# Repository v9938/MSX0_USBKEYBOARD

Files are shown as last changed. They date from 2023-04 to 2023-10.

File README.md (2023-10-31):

# MSX0 USB-Keyboard MBUS Stack  

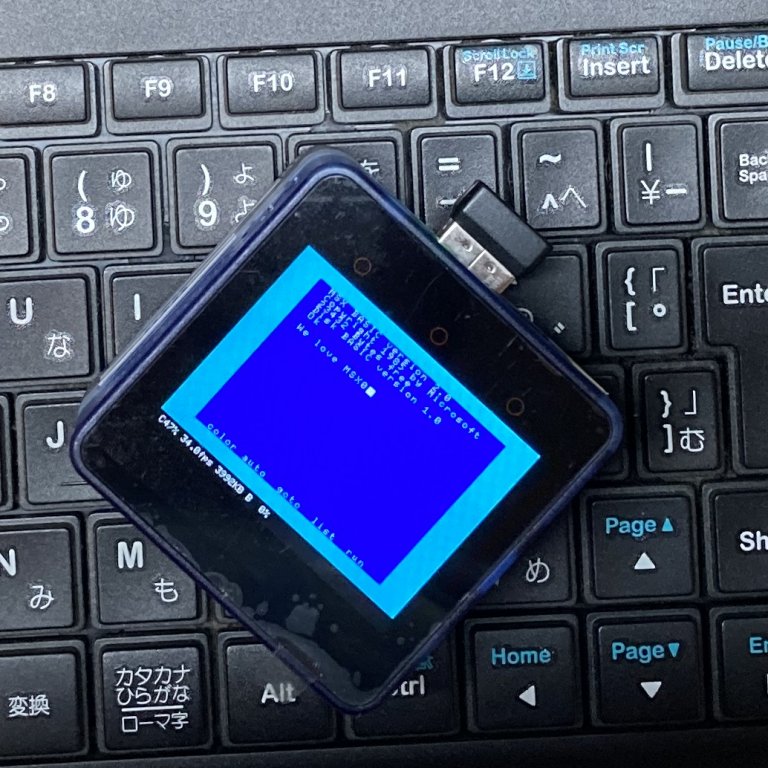
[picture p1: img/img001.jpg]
装置イメージ
  

MSX0 USB-Keyboard MBUS Stackは、別売のM5 Stack USB Module with MAX3421Eと一緒に使用することで  
M5 Faces Keyboard または Game Padと同等の機能を、USBキーボードやゲームパッドで実現するStackです。  
MSX0のKEYBOARDモードおよびGAME PADモードの両方に対応しています。  

## ■ MSX0製品版への対応について
(10/26更新）  
MSX0製品版(ver:0.05.04)への本製品の対応ですが、新しいスケッチに更新することで対応可能です。  

### Firmware (USB KEYBOARD版)
[USB KEYBOARD/MSX JOYSTICK対応版 Firmware](./Arduino/USBHIDBootKbd_MSX0/)  

sketchの書き込み方法は組み立て説明書の「Arduinoスケッチの書き込み」を参照ください。  
[組み立て説明書](./AssemblyManual/Assembly.md)

### 仕様上の制約について
動作は旧KEYBOARD仕様に準拠するため複数キーや押しっぱなしのキー認識が出来ません。  
また、MSX0の仕様上、旧キーボードモードでは本体Grove I2C_A端子との併用ができません。  
（Device I/O Error、またはMSX0の動作が止まります)

なお、新キーボードモードへの対応はKEY割り込み通知の信号が物理的に変わってしまったため、  
当該アダプタでは対応が不可能です。新基板にて対応を計画しています。ご了承ください。  

### キーボードモードとゲームパッドモードの切り替えについて
USBキーボードを接続していない場合やM5 USBモジュールを接続していない状態で起動した場合は  
GamePadモードになります。電源が入った状態で、USBを抜差すると一時的に動作がおかしくなる場合が  
ありますが、その際はMSX0をリセットしてください。  

## ■ 2種類のStack
頒布しているStackは、13mmと6.5mmの厚みが異なる2種類を頒布しています。  
この2つのStackは使用するFirmwareは一緒ですがMSX仕様のジョイスティック対応の有無の差があります。

### 共通機能  
USB KEYBOARD/JOYSTICK → MSX0 Keyboard変換  

### 6.5mm厚Stack
Socketの高さが違います(M5Stack用2 x 15ピンソケット)  
付属フレームがM5純正の成形品です　(M5 Plastic Frame for Proto Module)  

### 13mm厚Stack
MSX仕様JOYSTICK(DSUB9ピン) → MSX0 GamePad変換機能が追加されます。  
当該機能はStack単体でもMSX仕様のJOYSTICKの変換として使用することができます。  

Socketの高さが違います(M5-13.2モジュール用 ソケット)  
付属フレームは、オリジナルの3Dプリント品になります。　　

## ■ 使用イメージと基板写真

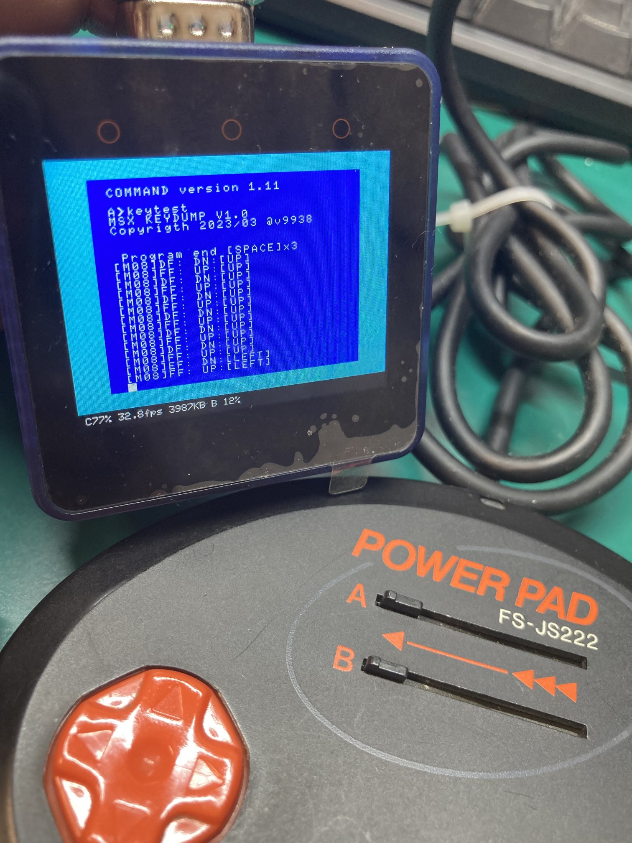
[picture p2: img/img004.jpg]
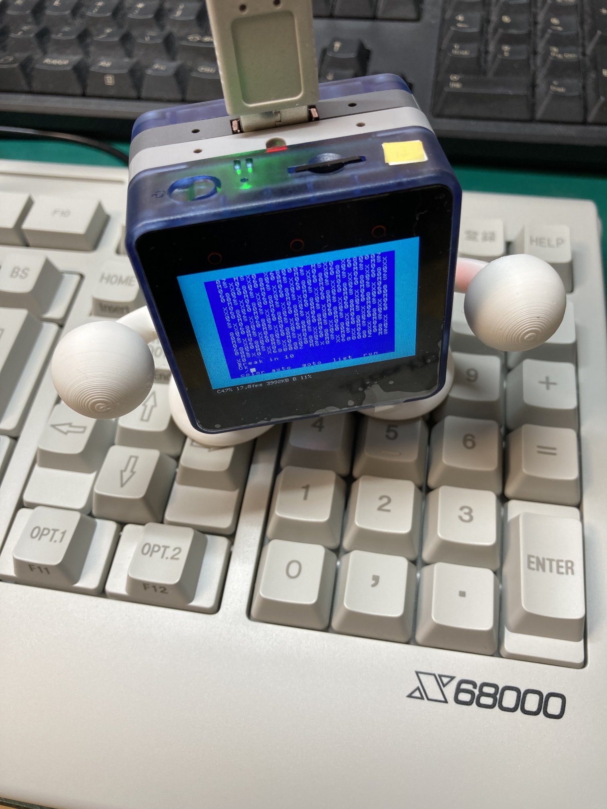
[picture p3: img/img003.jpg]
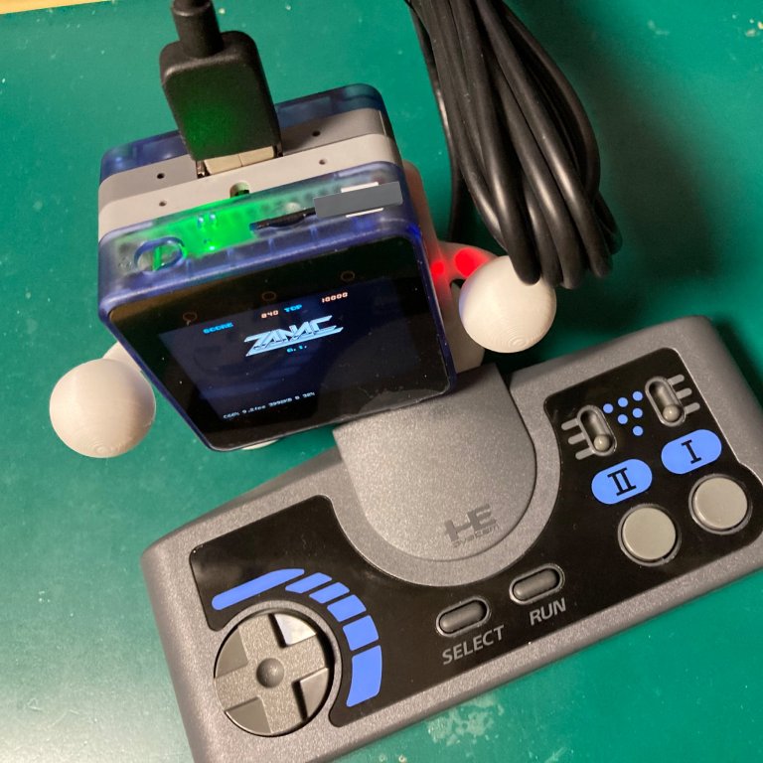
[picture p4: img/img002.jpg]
   
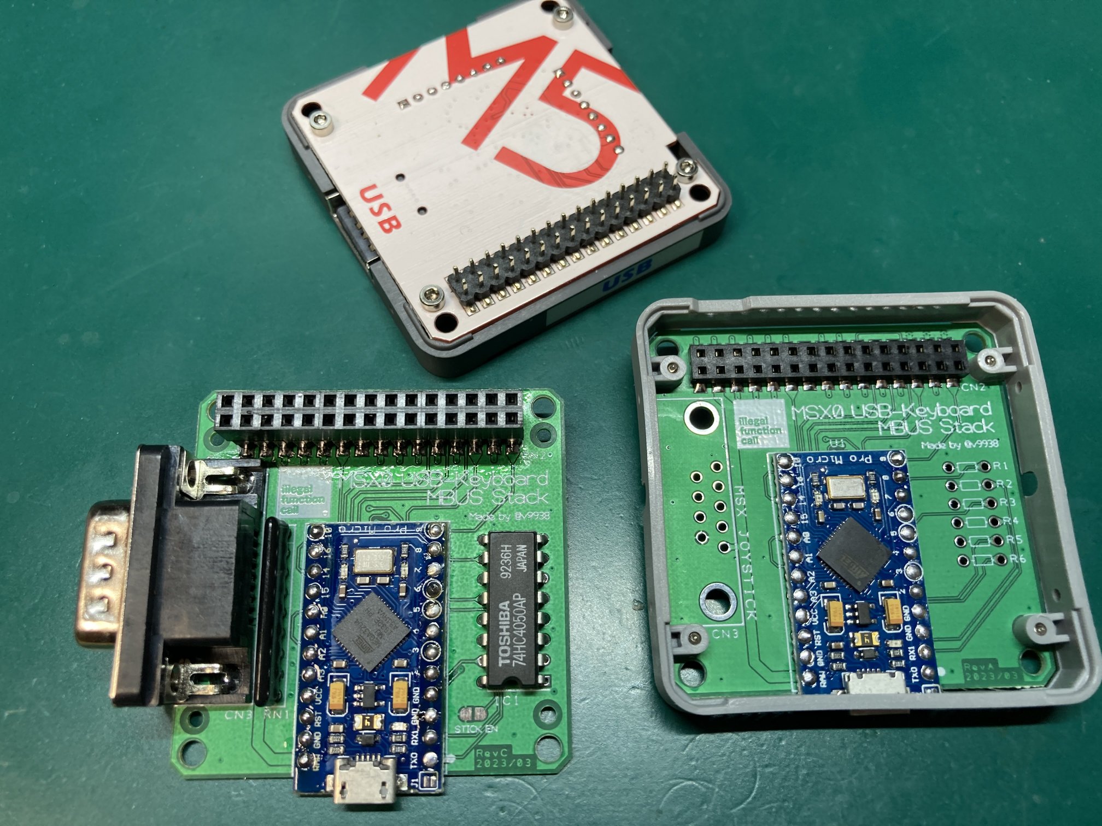
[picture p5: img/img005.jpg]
   

実際の動作は下記URLを参照してください。  
<https://twitter.com/i/status/1641843307184799746>  
<https://twitter.com/i/status/1641485580763807744>  

## ■ MSX0のキーボード実装仕様について   
現在配布中のMSX0では、MSXキーボードのキーボードについて全キーの割り付けがされていません。  
キーボードモードでは16msのみ当該キーがトグルされる仕様になっています。  
またゲームコントローラーモード以外で複数キーの同時入力および押し続けを行う事ができません。  

出来る限りオリジナルに近いキー配置や操作感にしたいのですが、MSX0の仕様により全く異なる操作感  
になる事をあらかじめご了承ください。  

本問題については、MSX0側の改良で改善される場合は本Stackも対応したいと思います。

## ■ MSX0のキーコード表   
本機は、以下のキーコード表を元に設計しました。  

#### I2Cアドレス 0x08　　
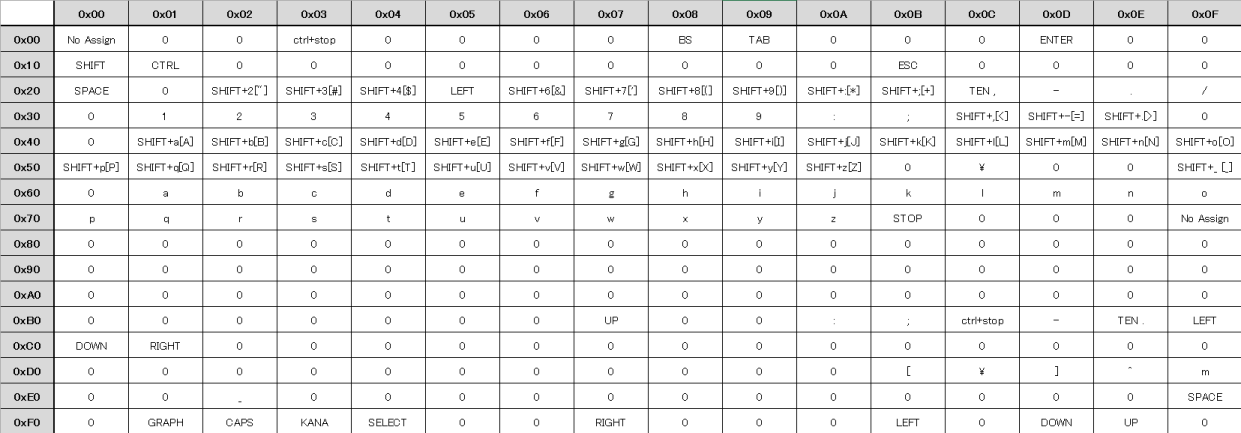
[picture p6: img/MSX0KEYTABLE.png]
  
[キーマップ (EXCEL形式)](./img/MSX0KEYTABLE.xlsx)
## ■ USBキーボードについて   
日本語対応USB 108/109キーボードに対応しています。  
Logicool社のUnifyingでの動作も確認できていますが、  
当該レシーバのように電源投入から立ち上がりが遅いキーボードは、  
電源投入直後のみ誤ってゲームパッドモードで認識される場合があります。  

その場合は、MSX0側のリセットボタンを押してMSX0を再起動するか、  
Configのキー設定をキーボードモード固定してください。  

<!-- 写真： -->

### 動作確認済みUSBキーボード
hp USBスリムスタンダードキーボード(日本語版109Aキーボード) N3R87AA#ABJ  
MSソリューションズ　MS-USBKBJP109BK  
Logicool Wireless Touch Keyboard K400  
Microsoft Wired keyboard 600
東プレ REALFORCE 108UBK SJ08B0  

## ■ USBゲームコントローラについて   
USBキーボード対応とファームが異なりますのでこちらを使う場合はファームを書き換えてください。  
USBゲームコントローラは以下の機種に対応しています。

### 動作確認済みUSBゲームコントローラ
SEGA Genesis Mini 3-Button Classic Controller MK-16500  
SEGA ファイティングパッド6B HAA-2552  
KONAMI(HORI) PCエンジンminiコントローラー HTG-002  
KONAMI(HORI) ターボパッド for PCエンジン mini HTG-003  
KONAMI(HORI) Core Grafx Mini mini Turbo Controller HTG-006  
SONY プレイステーション クラシック付属コントローラ SCPH-1000R  
8BitDo SN30 Pro  
SEGA アストロシティミニ コントロールパッド  
TAITO イーグレットツーミニ コントロールパッド  
TAITO イーグレットツーミニ コントロールパネル  
Matflash F300 Elite  
SONY PS4 DUALSHOCK 4 (CUH-ZCT2J)  
HORI FIGHTING STICK MINI  

## ■ 頒布するキットについて   

本製品は原則半田付けが必要なキット形式の頒布になります。  

家電のKENちゃん、SwitchScienceさんにて取り扱い予定です。  
配布の形態は、下記2形態になります。  

#### フルキット（基板 ＋ pro micro互換品 ＋その他パーツ ＋フレーム）
必要なパーツも、すべてセットになったキットです。  
パーツのハンダ付けとファームウェア書き込みの為にArduinoの開発環境が必要です。  

M5 Stack USB Moduleは別途購入してください。  
<https://shop.m5stack.com/products/usb-module>  
<https://www.switch-science.com/products/6061>  

#### 完成品（半田付け済、M5 Stack USB Module付属)
家電のKENちゃんのみの扱いになります。  
組み立て済で直ぐ使える状態になっています。  

## ■ 頒布先   

### フルキット
### ○6.5mm厚 USBのみ対応

#### Switch Science  
URL未定
<!-- <https://> -->

### ○13mm厚 MSX規格ジョイスティックポート有り

#### Switch Science  
URL未定
<!-- <https://> -->

### 完成品
### ○6.5mm厚 USBのみ対応
#### 家電のKENちゃん  
<https://www.kadenken.com/view/item/000000001590>

### ○13mm厚 MSX規格ジョイスティックポート有り
#### 家電のKENちゃん  
<https://www.kadenken.com/view/item/000000001589>

## ■ 組み立て説明書について  
[組み立て説明書](./AssemblyManual/Assembly.md)

## ■ 動作チェックソフト  
下記ツールでMSXからキーボード各キーの押した状態の確認を行う事ができます。  
[MSX-DOS KEYMATRIX チェックツール](./MSXKEYDUMP/keydump.com)

## ■ 本機の仕様について

|仕様  | 詳細 |
| - | - |
| 対応規格 | M5 module MBUS準拠 |
| Series Protocol | I2C Address 0x08 |
| 搭載マイコン | Atmel ATMEGA32U4 (3.3v 8MHz仕様) |
| 定格 | 5V 30mA (M5 Stack USB Moduleセット時)|
| 入出力端子 | micro USB B端子 (Firmware書き込み用、MSX0に電源供給可能)|
|  | MSXジョイスティック端子 (13mm厚のみ対応)|

## ■ 設計データ

### Firmware (USB KEYBOARD版)
[USB KEYBOARD/MSX JOYSTICK対応版 Firmware](./Arduino/USBHIDBootKbd_MSX0/)  
[USB KEYBOARD MSX0JOYPADモード Firmware](./Arduino/USBHIDKbd_MSX0_PADMODE/)  

### Firmware (USB JOYSTICK版)  
[USB JOYSTICK対応版 Firmware](./Arduino/USBHIDPad2MSX0/)  

### Firmware (組み立て動作チェック用)  

ひたすら'MSX0 'と入力されます。  
[組み立て動作チェック用 Firmware](./Arduino/TEST_MSX0KEYPADMode/)  

### 回路図
[回路図 (PDF版)](./PCB/KEYBOARDSTACK_Schematic.pdf)  
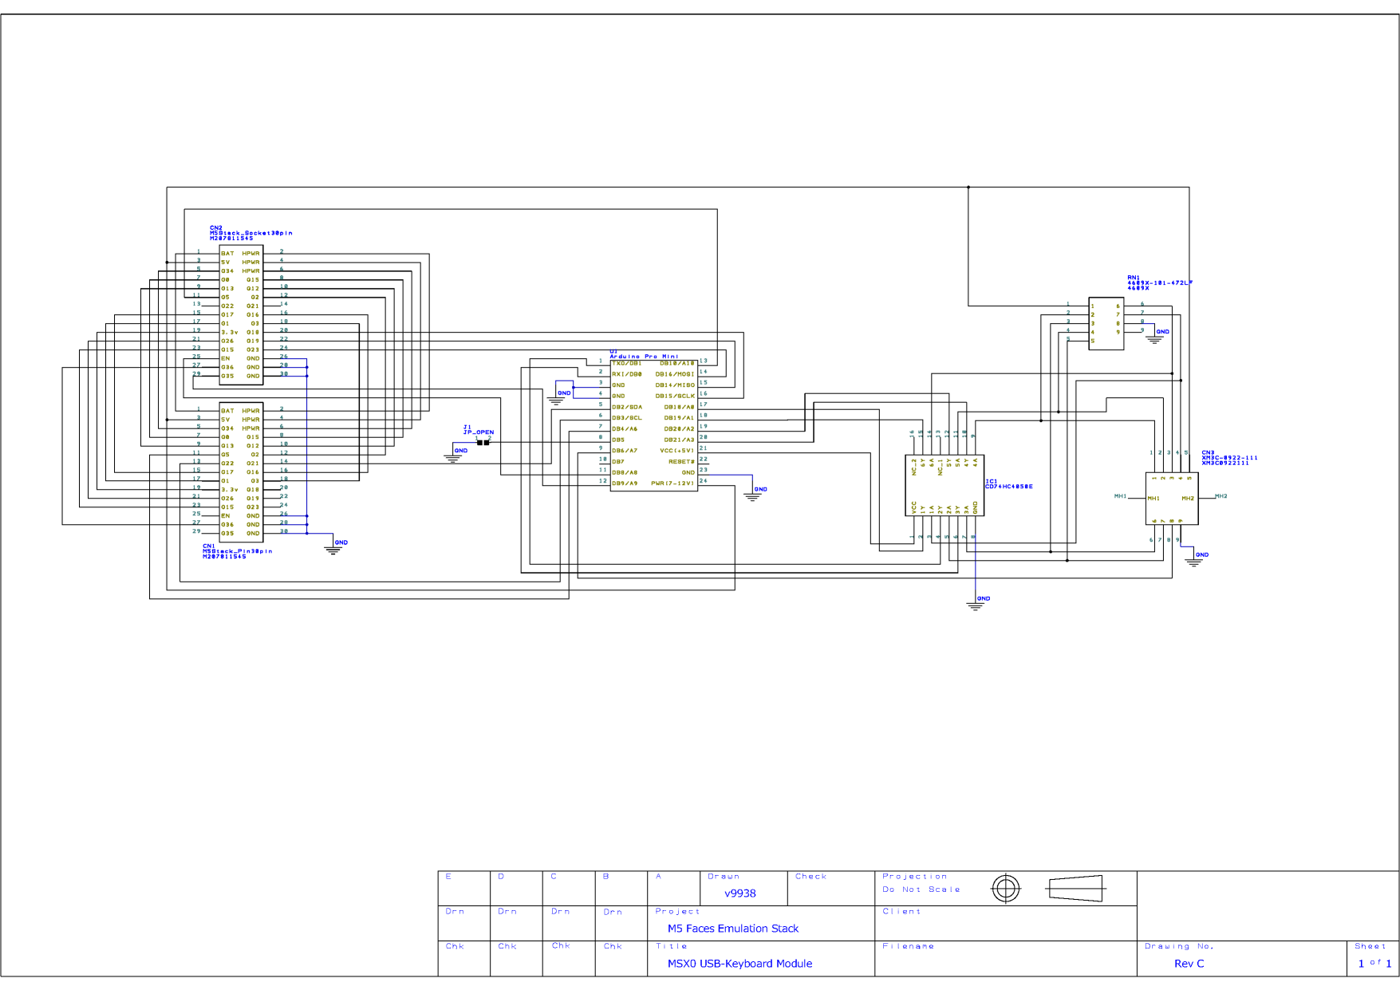
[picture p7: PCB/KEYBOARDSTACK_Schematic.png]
  

<!-- ### パーツリスト -->

### 基板
[PCB (PDF版)](./PCB/KEYBOARDSTACK_PCB.pdf)  
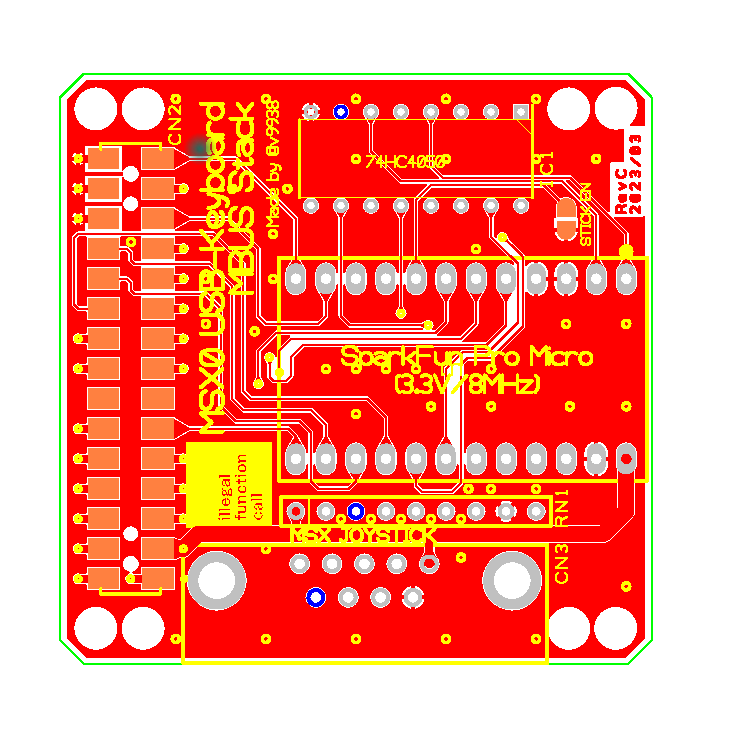
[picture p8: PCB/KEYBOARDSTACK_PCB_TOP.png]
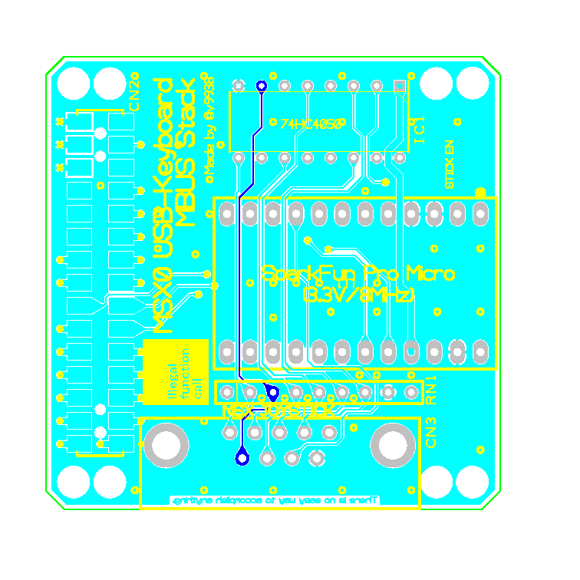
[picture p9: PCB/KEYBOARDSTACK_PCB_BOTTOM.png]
   
### 13mm厚フレーム  
[STLデータ](./PCB/Frame/m5stack-Stack.stl)

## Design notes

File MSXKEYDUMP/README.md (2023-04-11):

# MSX-DOS KEYMATRIX チェックツール  
MSXのキーマトリクスを直接読み取り、キーの状態を確認するツールです。
z88dkを使用して作成しています。

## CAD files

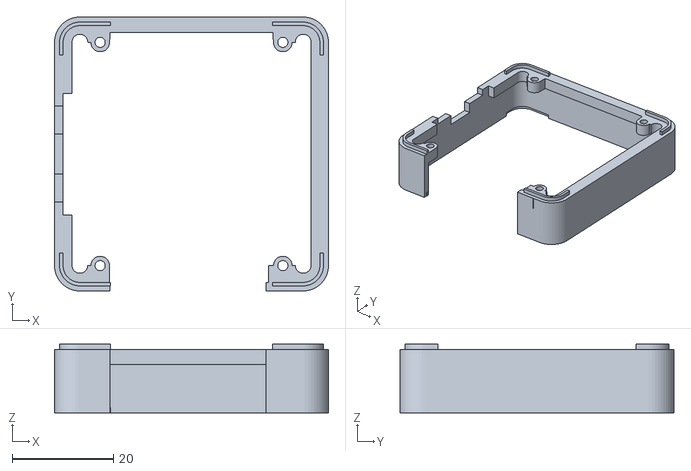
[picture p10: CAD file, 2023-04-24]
PCB/Frame/m5stack-Stack_RevB.stl
54.0 x 54.0 x 13.5

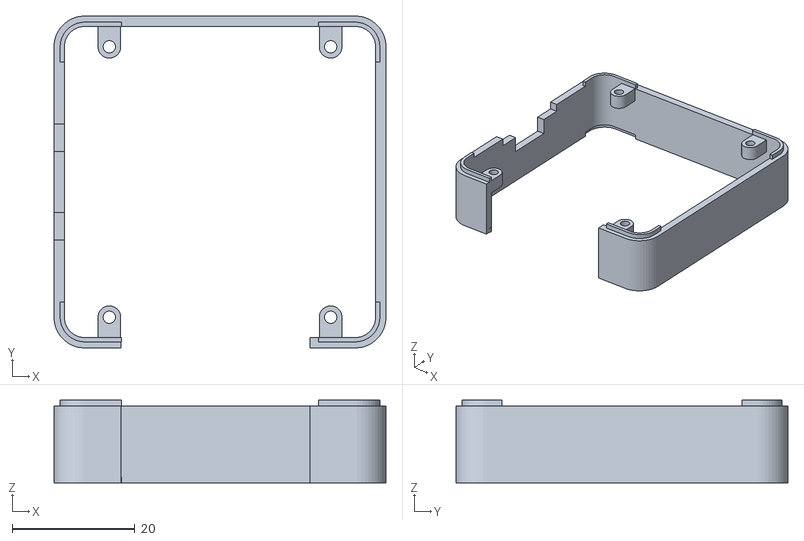
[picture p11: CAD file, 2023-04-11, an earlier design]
PCB/Frame/m5stack-Stack.stl
54.0 x 54.0 x 13.5

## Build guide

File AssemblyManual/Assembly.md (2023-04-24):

# MSX0 USB-Keyboard Stack 組み立てマニュアル

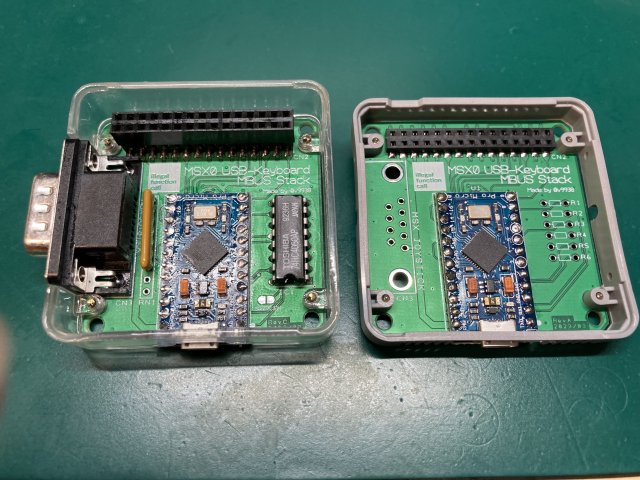
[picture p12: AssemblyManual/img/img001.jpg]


## パーツ一覧
下記パーツを同梱してあります。不足があった場合は連絡お願いします。  

### ■6.5mm厚キット 

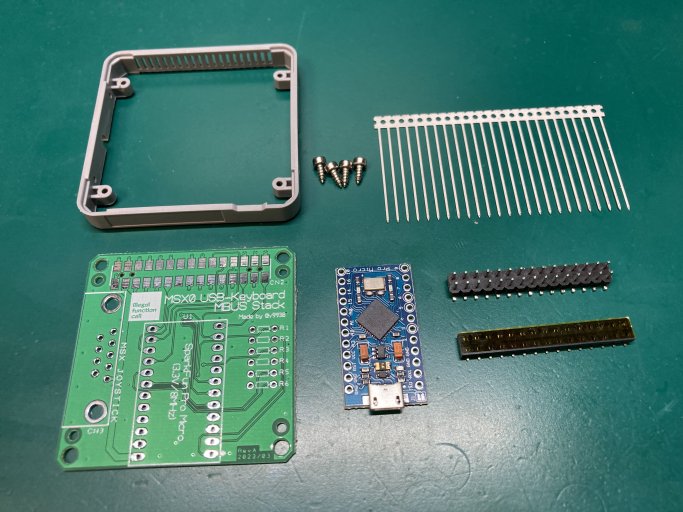
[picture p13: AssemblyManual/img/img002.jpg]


### 付属部品一覧

|Ref No|Part Name.|Qty|備考|
| :- |  :- |  :- |  :- |
|－|専用PCB|1||
|U1|sparkfun pro micro 3.3V 8MHz版 中華互換品|1|当サークルにて動作チェック済|
|CN1|M5純正 SMDピンヘッダー（オス側)|1|裏面実装のため、シルク印字ありません|
|CN2|M5純正 SMDピンヘッダー（メス側)|1||
|-|リードフレーム(24ピン分)|1|U1取り付け時に使用します　|
|-|M5純正 プロトタイプ用プラスチックフレーム|1|　|
|-|六角ネジ2mm |4| 基板固定用|

### ■13mm厚キット 

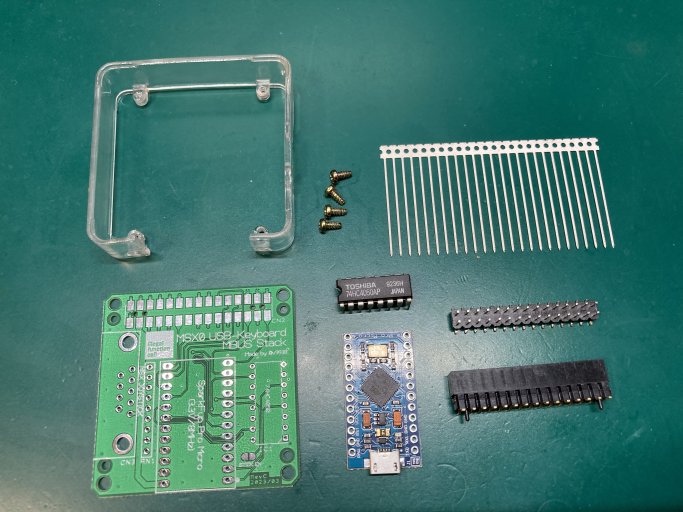
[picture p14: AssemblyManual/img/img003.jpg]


### 付属部品一覧

|Ref No|Part Name.|Qty|備考|
| :- |  :- |  :- |  :- |
|－|専用PCB|1||
|U1|sparkfun pro micro 3.3V 8MHz版 中華互換品|1|当サークルにて動作チェック済|
|CN1|M5純正 SMDピンヘッダー（オス側)|1|裏面実装のため、シルク印字ありません|
|CN2|M5純正 SMDピンヘッダー（メス側)|1||
|CN3|DSUB9ピンコネクタ (オス)|1||
|IC1|74HC4050相当品|1||
|RN1|抵抗アレー10k x 6素子|1|在庫の都合で10k x 8素子の場合があります|
|-|リードフレーム(24ピン分)|1|U1取り付け時に使用します　|
|-|専用13mm厚フレーム|1| 3Dプリント品　|
|-|ネジ2mm |4| 基板固定用|

## 組み立て時の注意点 (6.5mm厚/13mm厚 両方)

M5 Stackの制約として、ピンヘッダ側の凸部が2mm以下する必要があるようです。  
DIP部品を半田付けする場合は、基板面ギリギリまで部品の足をカットし半田付けしてください。  

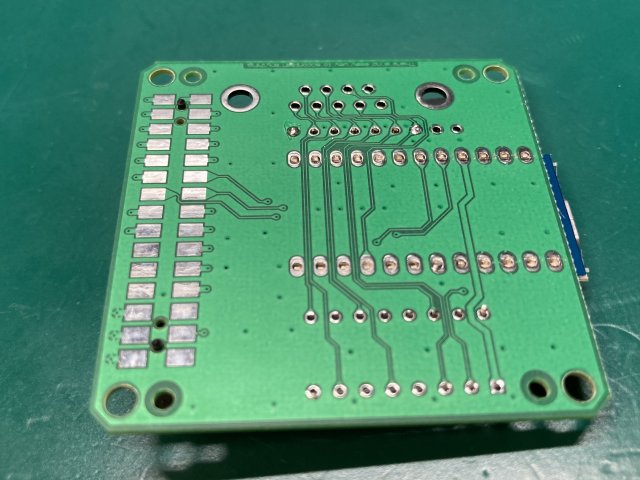
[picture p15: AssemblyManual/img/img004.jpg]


特に、D-SUBの固定金具は大きく飛び出るのでカットを忘れない様にしてください。

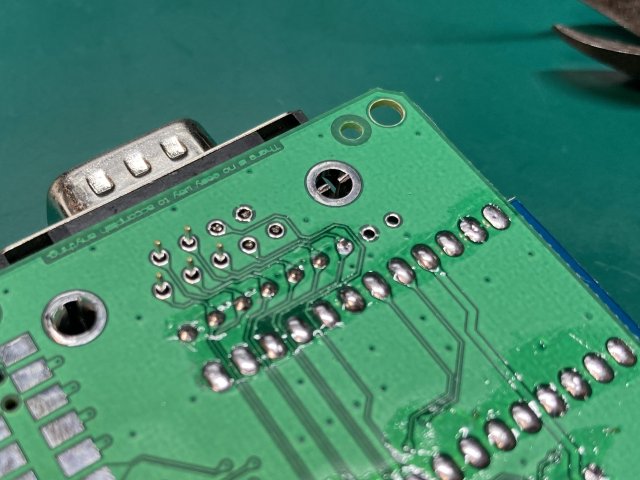
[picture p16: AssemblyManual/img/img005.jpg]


## 基板の組み立て(6.5mm厚)

### 1．U1に裏面からリードフレームを挿入します。

※耳の部分は後で折り取ります。  
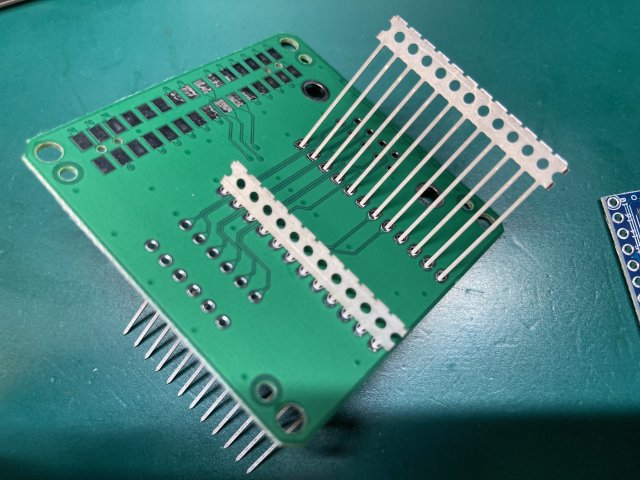
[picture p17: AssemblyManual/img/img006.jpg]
  

### 2．U1にpro microを挿入し、ハンダづけします。  

出来るだけピンが飛び出ない様にしてください。  
ハンダ付け前に折り曲げてカットしておくと見た目が綺麗です。 

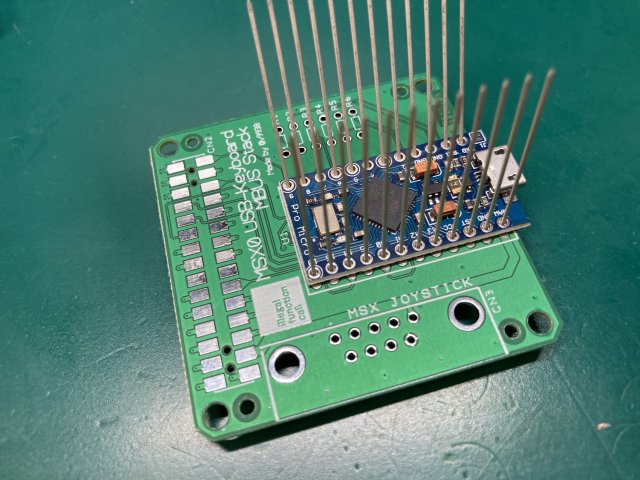
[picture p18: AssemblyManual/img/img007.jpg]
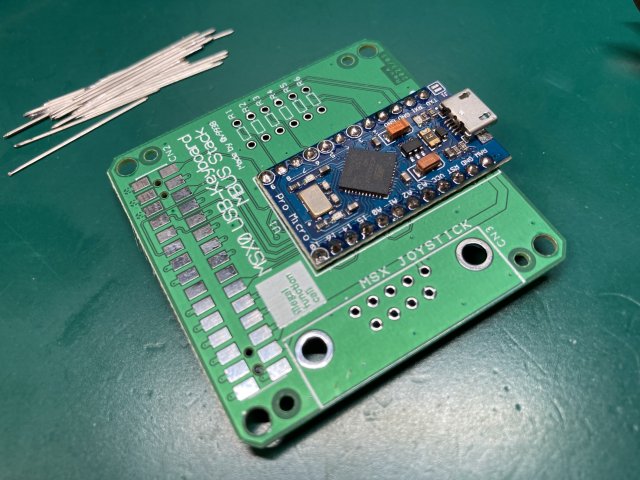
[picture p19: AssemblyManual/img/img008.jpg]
  

### 3．リードフレームの数回曲げて耳を折り取り、ハンダづけします。

曲げるのが堅い場合は、4ピンずつぐらいに分割してから曲げるとやりやすいと思います。

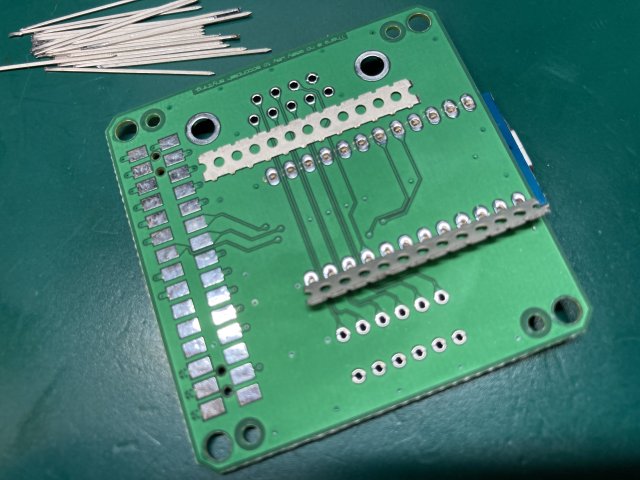
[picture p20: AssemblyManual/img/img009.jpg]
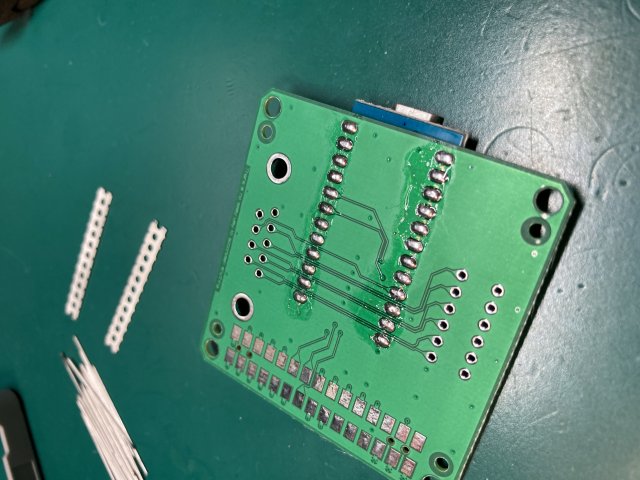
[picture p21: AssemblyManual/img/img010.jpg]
  

### 4．CN2 15x2コネクタ(メス)をハンダづけします。

位置合わせの基板の穴とコネクタのポッチを合わせて半田付けします。　　
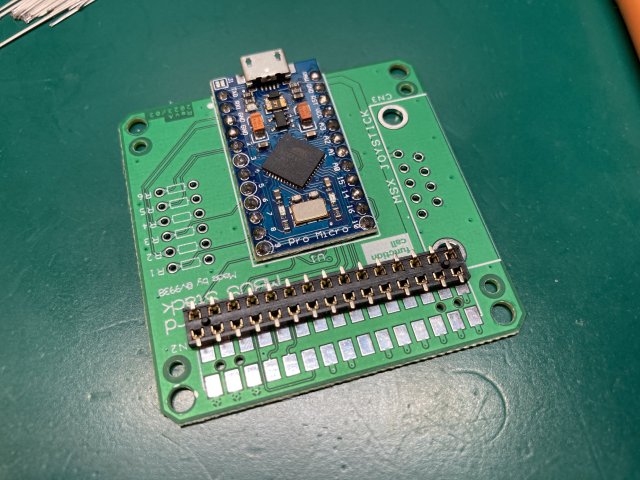
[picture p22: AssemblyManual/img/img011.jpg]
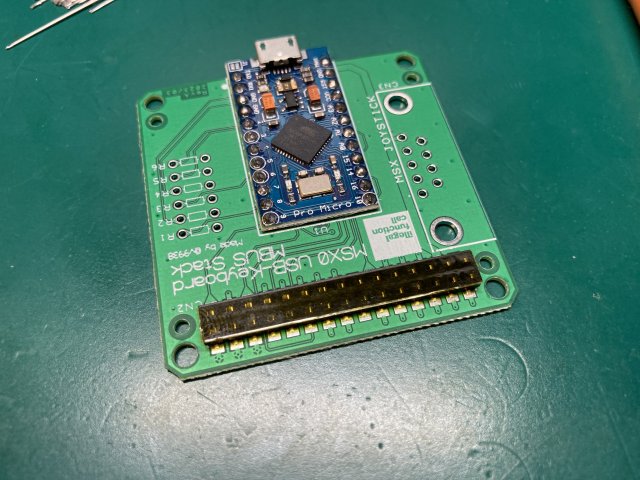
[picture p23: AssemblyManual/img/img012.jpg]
  

横からみた時は、このような感じになります。  
ハンダ量が多いとコネクタの端子までハンダが上がってくる事があるので、少量で手早く半田付けしてください。
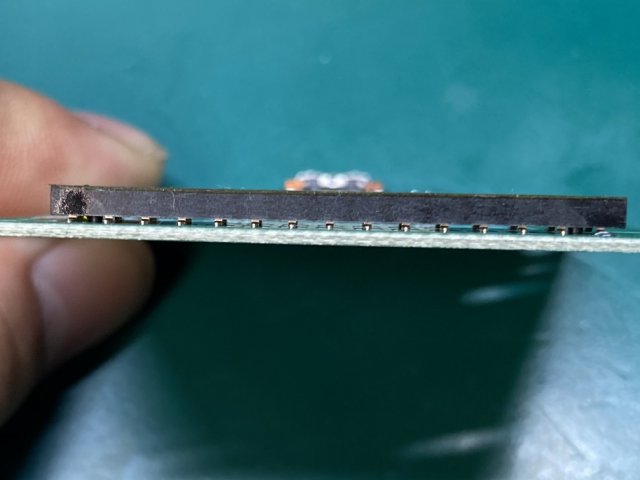
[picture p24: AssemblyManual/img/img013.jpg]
  

### 5．CN2 15x2コネクタ(オス)をハンダづけします。  

位置合わせの基板の穴とコネクタのポッチを合わせて半田付けします。  
コネクタが若干ずれやすいので注意してください。  
ここまで完了したら基板は完成です。引き続きフレームの加工を行ってください。  
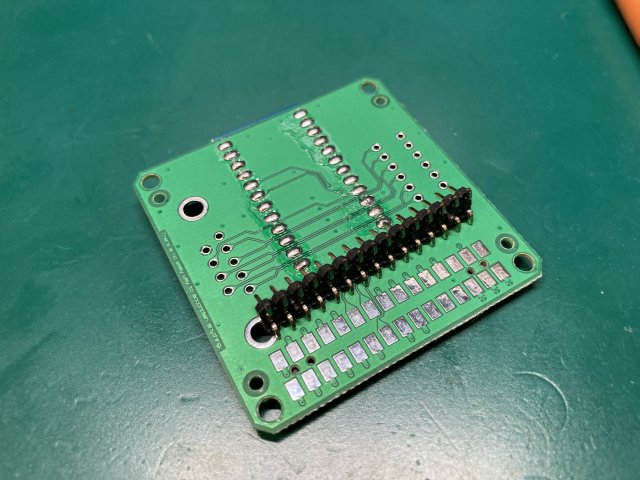
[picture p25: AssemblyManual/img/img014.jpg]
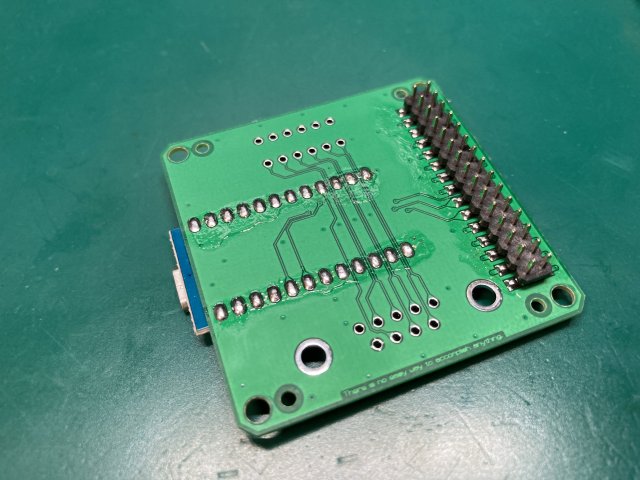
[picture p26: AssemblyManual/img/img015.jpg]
  

## フレームの加工(6.5mm厚)

基板の形状に合わせ、M5純正 プロトタイプ用プラスチックフレームの加工を行います。  

### 1．U1とフレームが干渉する部分をカットして折り取ります。  

マジックで着色している部分がカットする部分です。  
縦溝5つ分を左右に残す感じで、フレーム上をニッパーなどでカットし、  前後に曲げて折り取ります。  
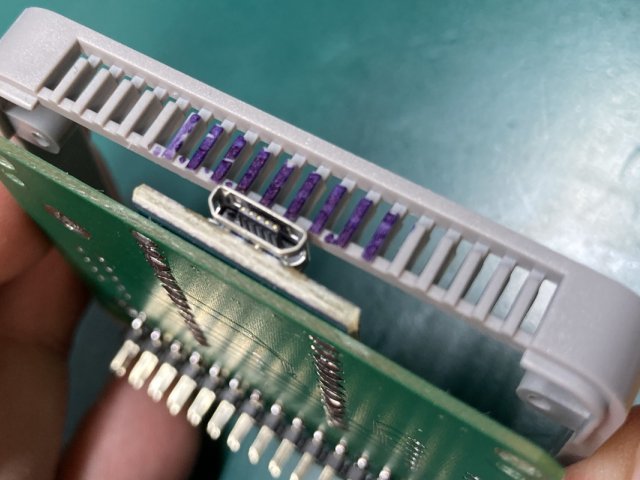
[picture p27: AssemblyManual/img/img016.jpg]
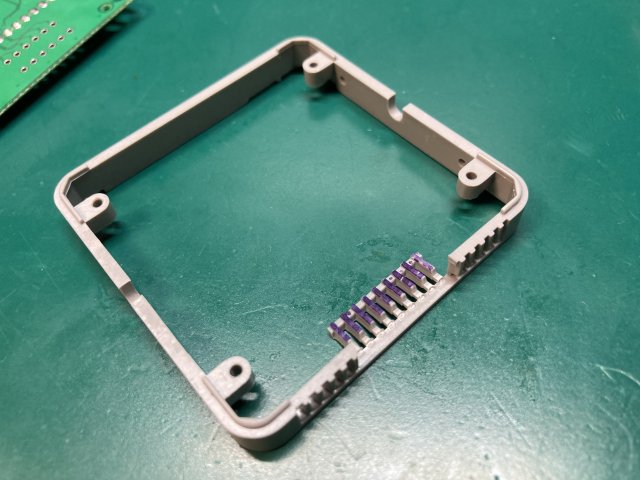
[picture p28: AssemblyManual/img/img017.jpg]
  

### 2．付属の六角ネジでフレームに基板を固定します。  
付属のネジをつかい基板をフレームに固定します。  
(1.5mmの六角レンチはM5に付属しています）  
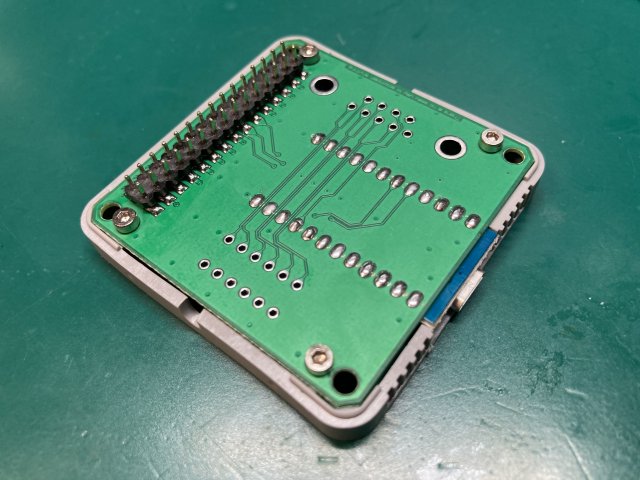
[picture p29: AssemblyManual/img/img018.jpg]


完成です。次にArduinoスケッチの書き込みをおこなってください。


## 基板の組み立て(13mm厚)

### 1．U1に裏面からリードフレームを挿入します。

※耳の部分は後で折り取ります。  
  

### 2．U1にpro microを挿入し、ハンダづけします。  

出来るだけピンが飛び出ない様にしてください。  
ハンダ付け前に折り曲げてカットしておくと見た目が綺麗です。 

  

### 3．リードフレームの数回曲げて耳を折り取り、ハンダづけします。

曲げるのが堅い場合は、4ピンずつぐらいに分割してから曲げるとやりやすいと思います。

  

### 4．IC1 74HC4050/RN1 10KΩをハンダづけします。

いずれのパーツも向きがあるので、注意してください。    
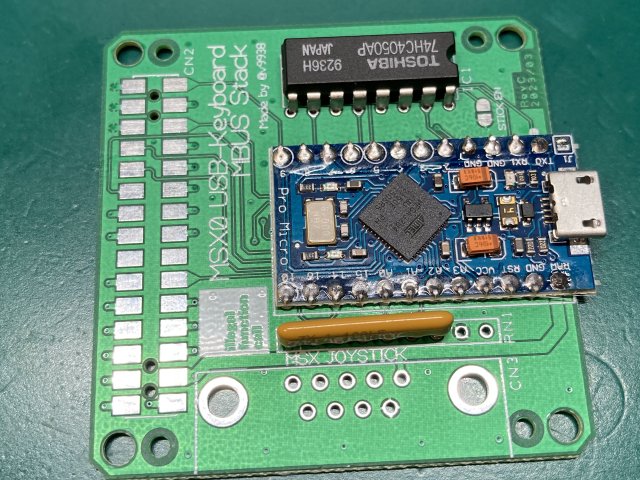
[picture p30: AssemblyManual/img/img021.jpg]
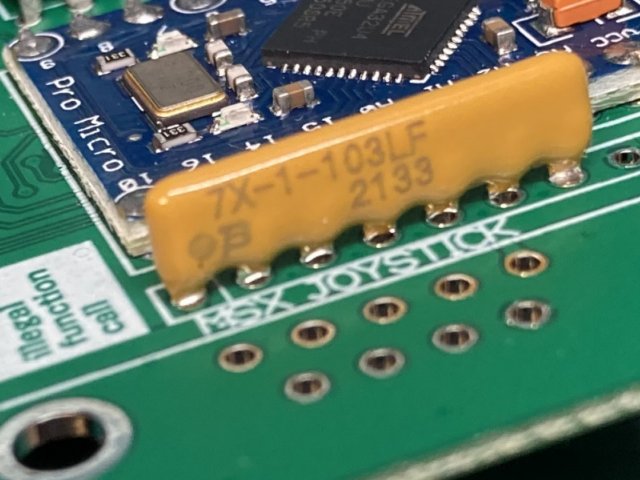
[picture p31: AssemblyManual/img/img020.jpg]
  

### 5．CN3 15x2コネクタ(メス)をハンダづけします。

位置合わせの基板の穴とコネクタのポッチを合わせて半田付けします。  
近傍のD-SUB9ピンのネジ穴にハンダが誤って乗りやすいので、事前にマスキングした方が良いと思います。  
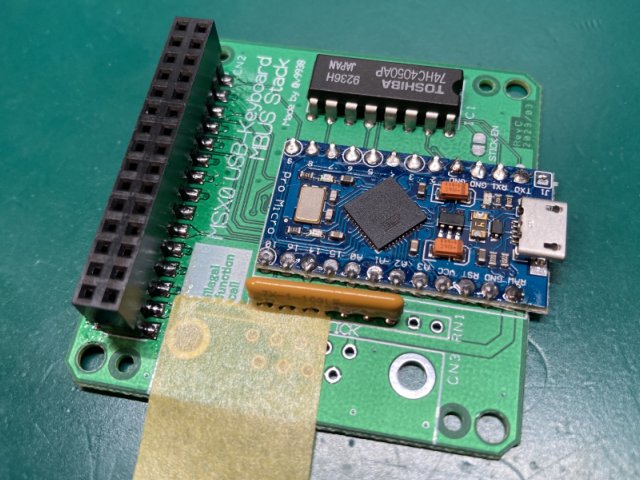
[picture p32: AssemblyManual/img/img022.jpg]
   

### 6．CN3 DSUB9ピン2コネクタ(オス)をハンダづけします。

裏面への飛び出し量に注意してください、ツメの金属は硬いのですが、頑張ってカットしてください。DD
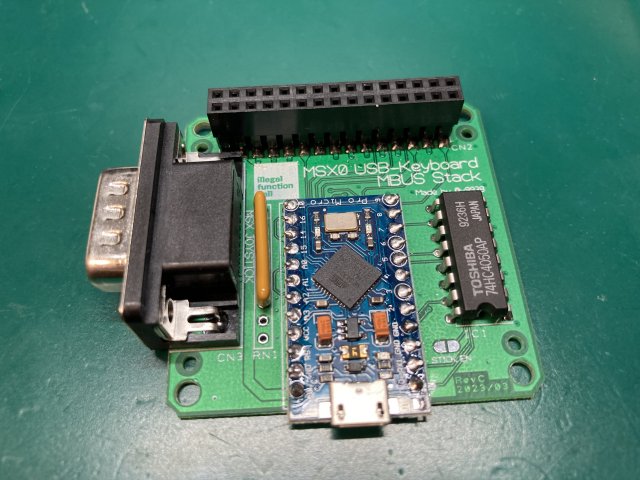
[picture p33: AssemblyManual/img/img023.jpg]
   

### 7．ハンダ面にCN2の15x2コネクタ(オス)をハンダづけします。  

位置合わせの基板の穴とコネクタのポッチを合わせて半田付けします。  
コネクタが若干ずれやすいので注意してください。  
ここまで完了したら基板は完成です。引き続きフレームのネジ止めを行ってください。  
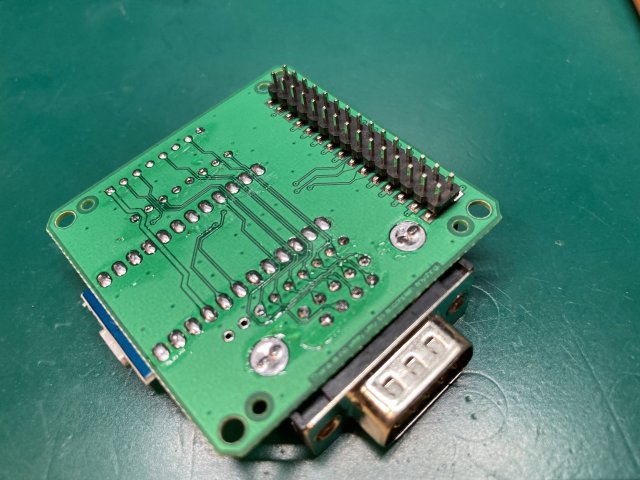
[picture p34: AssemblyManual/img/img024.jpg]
 　

## フレームへの固定(13mm厚)

基板をフレームにネジを使い固定します。  
フレームの穴を基板の穴と合わせて、付属ネジで適切なトルクでねじ込み固定してください。  
フレームは3Dプリント品のため、ゆがみが有る場合がありますが、ネジで固定すると修正されます。  
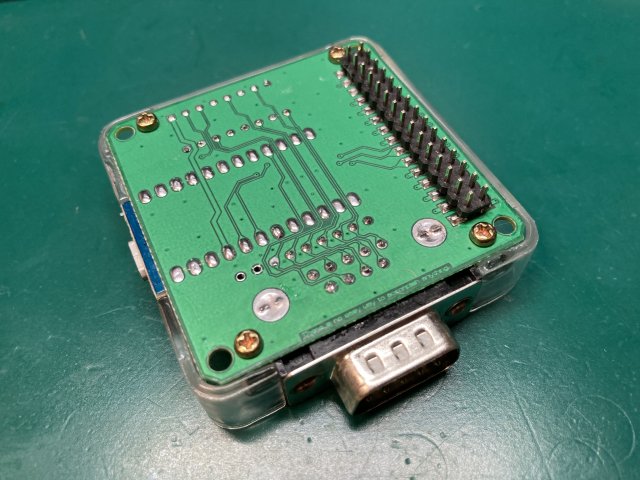
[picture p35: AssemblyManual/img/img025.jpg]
   

完成です。次にArduinoスケッチの書き込みをおこなってください。  
  

## Arduinoスケッチの書き込み

ボード設定、スケッチのコンパイルと書き込みの順に進めていきます。  
なお、Arduinoのインストールや細かい使い方はここでは割愛します。  

### 1.　sparkfun pro micro のボード設定ファイルをインストール  

Arduino.cc公式のボードでは無いため、ボード設定が必要になります。  

[ファイル]→[環境設定]→[追加のBoard Manager]に下記を入力

`https://raw.githubusercontent.com/sparkfun/Arduino_Boards/master/IDE_Board_Manager/package_sparkfun_index.json`

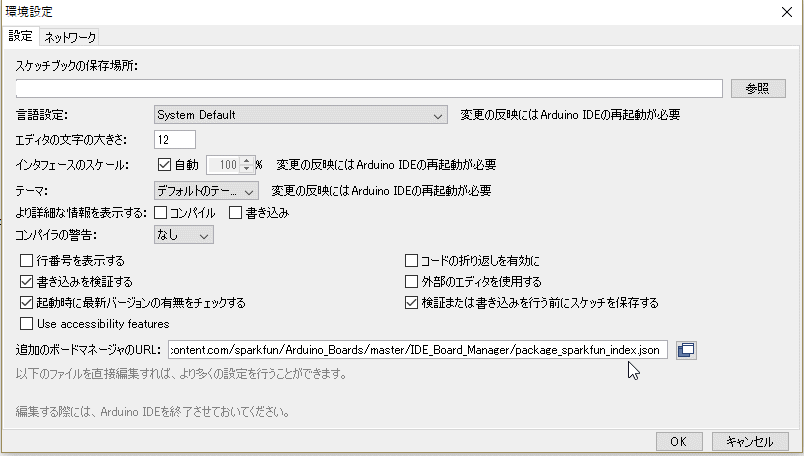
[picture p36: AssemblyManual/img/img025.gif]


[ツール]→[ボード]→[ボードマネージャー]を開いて、"sparkfun"を検索。
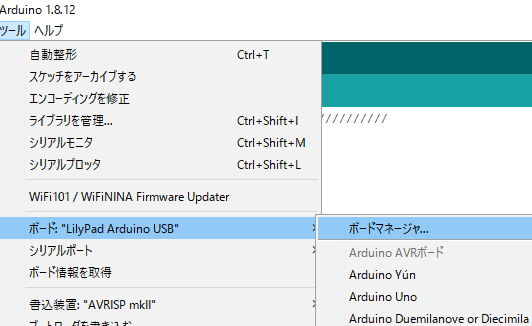
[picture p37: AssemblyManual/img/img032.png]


SparkFun AVR Boardsのパッケージをインストールする。
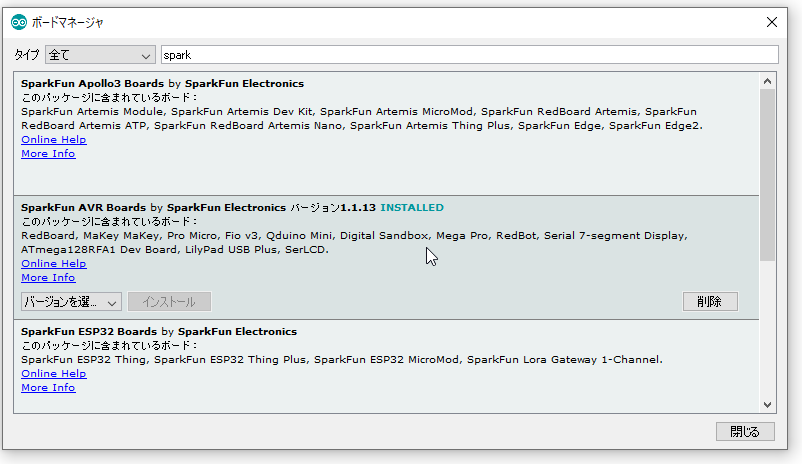
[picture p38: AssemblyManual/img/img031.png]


参考：
https://learn.sparkfun.com/tutorials/pro-micro--fio-v3-hookup-guide#windows_boardaddon

### 2.　ボードとCPU設定
ボードをsparkfun Pro Microに設定します。  
プロセッサー設定は3.3V 8MHzのボード設定をします  

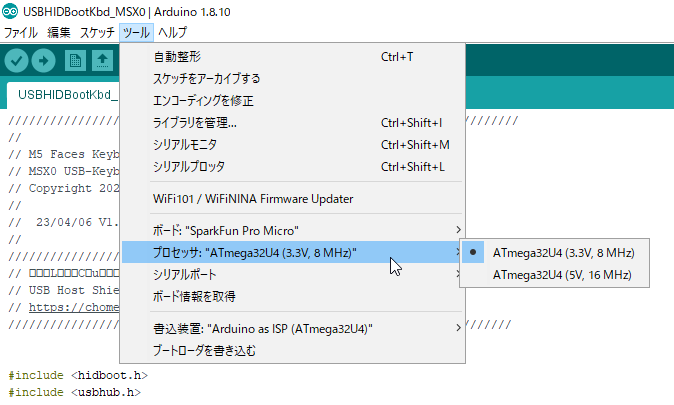
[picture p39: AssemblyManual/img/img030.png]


### 3.　プログラムのコンパイルと書き込み
COMポートをUSBシリアルの番号に設定してください。  
「マイコンボードに書き込む」のアイコンをクリックし、プログラムの書き込みを完了してください。  

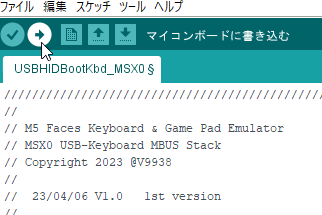
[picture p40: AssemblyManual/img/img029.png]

  

これで準備が完了しました。

## 動作チェック  

### USB Stackの動作確認
上から[M5 Core2 (MSX0)]→[本Stack]→[M5 USB Host Shield]順にスタックしてください。  
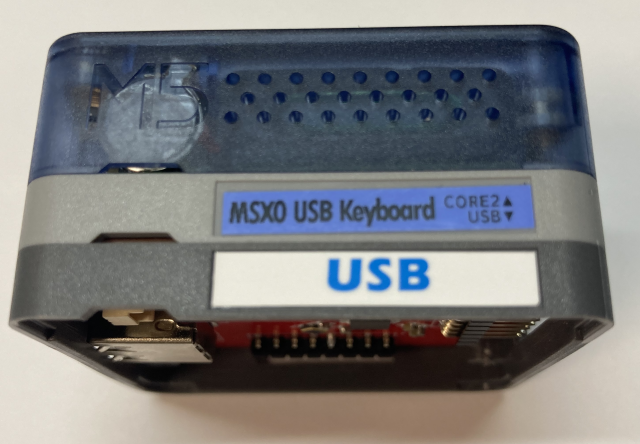
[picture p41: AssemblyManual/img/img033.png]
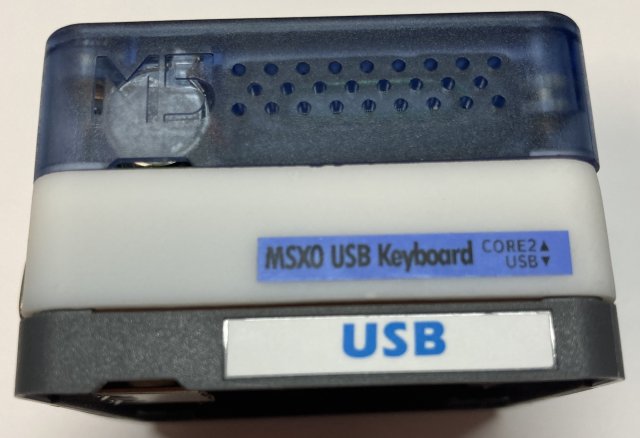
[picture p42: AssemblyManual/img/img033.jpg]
　

次にUSBキーボードをUSB端子に接続してください。  
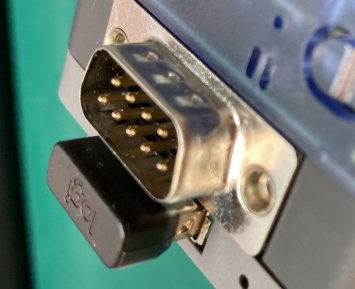
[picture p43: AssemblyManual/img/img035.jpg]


MSX0の電源を入れるとUSBキーボードでキー入力が可能です。  
なお、無線タイプの場合、キーボードの初期化時間の都合で認識出来ない場合があります。  
その場合は、MSX0のリセットボタンを一度押してみてください。  

### MSXジョイスティックポートの動作確認(13mm版のみ)
USB端子に何も接続していないとき、またはUSB Stackを重ねない場合に、  
本機のMSX仕様のジョイスティック端子が使えます。  
このモードで、すべての方向とTrig0/1がすべて問題無いか確認してみてください。

## 動作確認ソフトについて
動作確認ソフトとして、MSXのキーマトリクスを直接読み取り、キーの状態を確認するツール  
MSXDOSで動作する「keydump.com」を同梱しています。  

https://github.com/v9938/MSX0_USBKEYBOARD/tree/main/MSXKEYDUMP

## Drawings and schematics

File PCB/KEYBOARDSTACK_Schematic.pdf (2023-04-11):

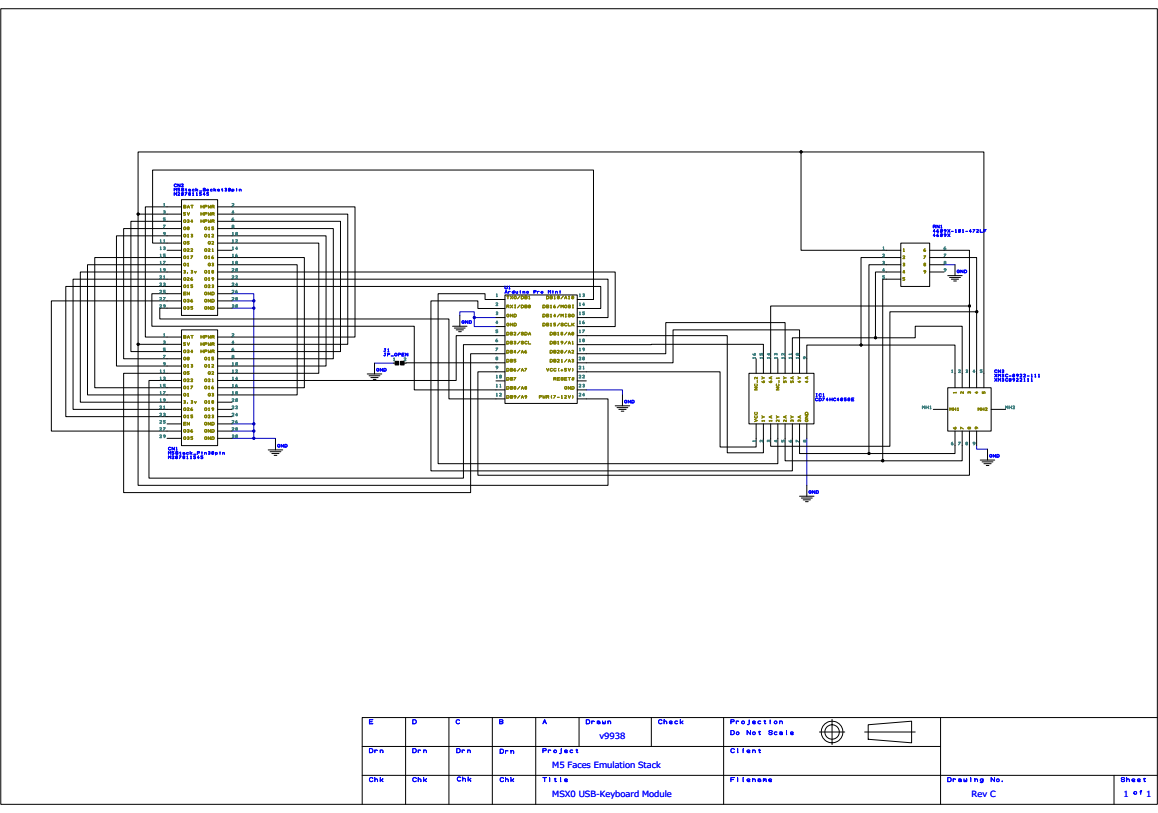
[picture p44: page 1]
MSX0 USB-Keyboard Module; Rev C

M5 Faces Emulation Stack

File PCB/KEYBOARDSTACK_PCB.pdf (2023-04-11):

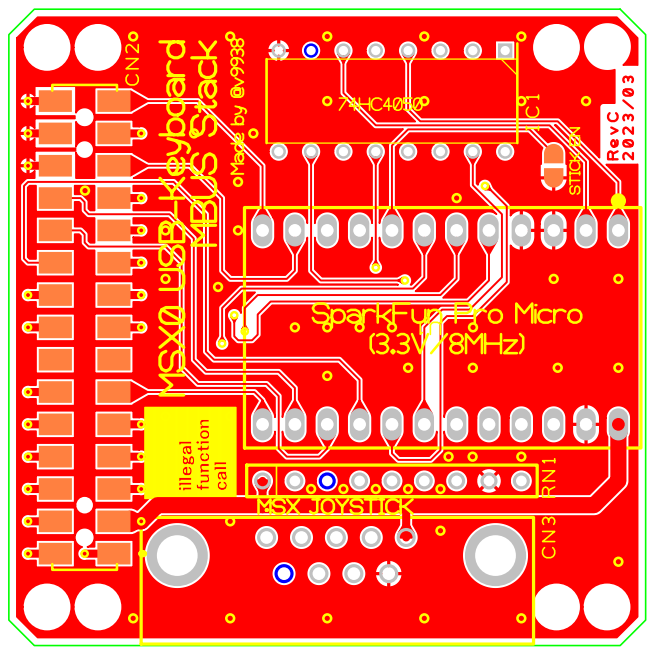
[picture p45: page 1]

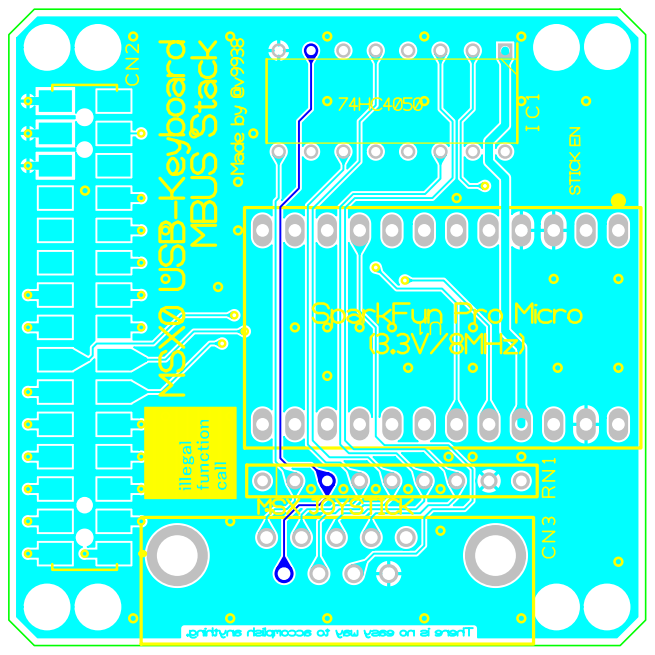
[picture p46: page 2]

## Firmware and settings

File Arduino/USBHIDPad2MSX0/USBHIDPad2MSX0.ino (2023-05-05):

////////////////////////////////////////////////////////////////////////
//
// M5 Faces Keyboard & Game Pad Emulator
// MSX0 USB-GamePad MBUS Stack
// Copyright 2023 @V9938
//	
//	23/04/29 V1.0		1st version
//	23/05/06 V1.1		Add some supported controllers
//
////////////////////////////////////////////////////////////////////////
// 下記ライブラリを使用しています。
// USB Host Shield library Version 2.0
// https://chome.nerpa.tech/arduino_usb_host_shield_projects/
////////////////////////////////////////////////////////////////////////

#include <usbhid.h>
#include <hiduniversal.h>
#include <usbhub.h>
#include <Wire.h>

// UARTにデバッグMessageを表示するか（通常は無効)
//#define DEBUG_PRINT 
//#define USB_RAW_DISPLAY

#define FACES_KEYBOARD_I2C_ADDR 0x08
#define FACES_GAMEPAD_MODE

#define Set_Bit(val, bitn)    (val |=(1<<(bitn)))
#define Clr_Bit(val, bitn)     (val&=~(1<<(bitn)))
#define Get_Bit(val, bitn)    (val &(1<<(bitn)) )

//KEY PORTB
//IRQ PC0
#define IRQ_1 Set_Bit(PORTD,4)
#define IRQ_0 Clr_Bit(PORTD,4)

unsigned char JoyCl = 0;

// Support Controller
#define JoyClMax			VID0F0DPID00ED	//最終コントローラID

#define UNKNOWN_VIDPID		255				//非対応コントーラID

#define VID0CA3PID0025		0				//MD PAD USB (MK-16500)
#define VID0CA3PID0024		1				//MD 6B PAD USB (HAA-2522)

// Byte3 X方向 LEFT 0x00-0x7f-0xff RIGHT
// Byte4 Y方向 UP   0x00-0x7f-0xff DOWN
// Byte5 0x4F A / 0x2F B / 0x8F X / 0x1F Y 
// Byte6 0x02 C / 0x20 Start / 0x01 Z / 0x10 Mode

#define VID0F0DPID0138		2				//KONAMI PCEmini Controller(HT-002)

// Byte0 II 0x02 / I 0x04 
// Byte1 Select 0x01 / Start 0x02
// Byte2 HATSW (上右)12345678(上) 0x0f (NoKey)

#define VID0810PIDE501		3				//NB NES USB Controller
// Byte3 X方向 LEFT 0x00-0x7f-0xff RIGHT
// Byte4 Y方向 UP   0x00-0x7f-0xff DOWN
// Byte5 0x1F A / 0x2F B
// Byte6 0x20 Start / 0x10 Select

#define VID054CPID0CDA		4				//SONY PSX mini Controller (SCPH-1000R)
// Byte0 △ 0x01 / ○ 0x02 / × 0x04 / □ 0x08 / L2 0x10 / R2 0x20 / L1 0x40 / R1 0x80
// Byte1 HAT X方向 LEFT 0x00 - 0x04 - 0x08 RIGHT Y方向 UP 0x00 - 0x10 - 0x20 DOWN  SEL 0x01 START 0x02
//


// V1.1 Added
// --------------------------------------------------
//
#define VID2DC8PID2101		5				//8BitDo SN30 Pro
// 8BitDo SN30 Pro
//VID: 0x2DC8 PID: 0x2101 Connected.
//BUF: 01000008FF7FFF7F　←挿した後の初期値
//BUF: 01 00 00 00FF7FFF7F　←十字キー[上]を押した ★
//BUF: 01 00 00 04FF7FFF7F　←十字キー[下]を押した ★
//BUF: 01 00 00 06FF7FFF7F　←十字キー[左]を押した ★
//BUF: 01 00 00 02FF7FFF7F　←十字キー[右]を押した ★
//BUF: 01 01 00 08FF7FFF7F　←ボタン[A]を押した ★A(TRIGGER1)
//BUF: 01 02 00 08FF7FFF7F　←ボタン[B]を押した ★B(TRIGGER3)
//BUF: 01 08 00 08FF7FFF7F　←ボタン[X]を押した ◎B(TRIGGER3)
//BUF: 01 10 00 08FF7FFF7F　←ボタン[Y]を押した ◎A(TRIGGER1)
//BUF: 01 00 01 08FF7FFF7F　←ボタン[LT]を押した
//BUF: 01 00 02 08FF7FFF7F　←ボタン[RT]を押した
//BUF: 01 40 00 08FF7FFF7F　←ボタン[LB]を押した
//BUF: 01 80 00 08FF7FFF7F　←ボタン[RB]を押した
//BUF: 01 00 08 08FF7FFF7F　←ボタン[START]を押した ★START
//BUF: 01 00 04 08FF7FFF7F　←ボタン[SELECT]を押した ★SELECT
//BUF: 01 00 10 08FF7FFF7F　←ボタン[HOME]を押した
//
// Byte1: button [RB LB 0 Y    | X     0       B A]
// Byte2: button [0  0  0 HOME | START SELECT RT LT
// Byte3: HAT
// --------------------------------------------------


#define VID0CA3PID0027		6				//SEGA アストロシティミニ コントロールパッド
// SEGA アストロシティミニ コントロールパッド
// ※SEGA MDMINI系と同じ配置
//VID: 0xCA3 PID: 0x27 Connected.
//BUF: 01 7F 7F 7F 7F 0F 00 00　←挿した後の初期値
//BUF: 01 7F 7F 7F 00 0F 00 00　←十字キー[上]を押した ★
//BUF: 01 7F 7F 7F FF 0F 00 00　←十字キー[下]を押した ★
//BUF: 01 7F 7F 00 7F 0F 00 00　←十字キー[左]を押した ★
//BUF: 01 7F 7F FF 7F 0F 00 00　←十字キー[右]を押した ★
//BUF: 01 7F 7F 7F 7F 4F 00 00　←ボタン[D]を押した ◎B(TRIGGER3)
//BUF: 01 7F 7F 7F 7F 2F 00 00　←ボタン[E]を押した ◎A(TRIGGER1)
//BUF: 01 7F 7F 7F 7F 0F 02 00　←ボタン[F]を押した ◎B(TRIGGER3)
//BUF: 01 7F 7F 7F 7F 8F 00 00　←ボタン[A]を押した ★A(TRIGGER1)
//BUF: 01 7F 7F 7F 7F 1F 00 00　←ボタン[B]を押した ★B(TRIGGER3)
//BUF: 01 7F 7F 7F 7F 0F 01 00　←ボタン[C]を押した ◎A(TRIGGER1)
//BUF: 01 7F 7F 7F 7F 0F 20 00　←ボタン[START]を押した ★START
//BUF: 01 7F 7F 7F 7F 0F 10 00　←ボタン[CREDIT]を押した ★SELECT
//
// Byte3 X方向 LEFT 0x00-0x7f-0xff RIGHT
// Byte4 Y方向 UP   0x00-0x7f-0xff DOWN
// Byte5 button [ A D E     B      | 1 1 1 1 ]
// Byte6 button [ 0 0 START CREDIT | 0 0 F C ]

#define VID0AE4PID0702		7				//TAITO イーグレットツーミニ コントロールパッド
#define VID0AE4PID0703		8				//TAITO イーグレットツーミニ コントロールパネル
// TAITO イーグレットツーミニ コントロールパッド(PID: 0x702)
// TAITO イーグレットツーミニ コントロールパネル(PID: 0x703)
//
//VID: 0xAE4 PID: 0x702 Connected.
//VID: 0xAE4 PID: 0x703 Connected.
//BUF: 00 00 7F 7F 00 00 00 00　←挿した後の初期値
//BUF: 00 00 7F 00 00 00 00 00　←十字キー[上]を押した ★
//BUF: 00 00 7F FF 00 00 00 00　←十字キー[下]を押した ★
//BUF: 00 00 00 7F 00 00 00 00　←十字キー[左]を押した ★
//BUF: 00 00 FF 7F 00 00 00 00　←十字キー[右]を押した ★
//BUF: 10 00 7F 7F 00 00 00 00　←ボタン[A]を押した ★A(TRIGGER1)
//BUF: 04 00 7F 7F 00 00 00 00　←ボタン[B]を押した ★B(TRIGGER3)
//BUF: 02 00 7F 7F 00 00 00 00　←ボタン[C]を押した ◎A(TRIGGER1)
//BUF: 00 01 7F 7F 00 00 00 00　←ボタン[D]を押した ◎B(TRIGGER3)
//BUF: 08 00 7F 7F 00 00 00 00　←ボタン[E]を押した ◎A(TRIGGER1)
//BUF: 01 00 7F 7F 00 00 00 00　←ボタン[F]を押した ◎B(TRIGGER3)
//BUF: 40 00 7F 7F 00 00 00 00　←ボタン[真ん中のピンク]を押した ★SELECT
//BUF: 80 00 7F 7F 00 00 00 00　←ボタン[真ん中の青]を押した ★START
//BUF: 00 02 7F 7F 00 00 00 00　←ボタン[真ん中の白]を押した
//
// Byte0 button [ BLUE PINK 0 A | E B C     F ]
// Byte1 button [ 0    0    0 0 | 0 0 WHITE D ]
// Byte2 X方向 LEFT 0x00-0x7f-0xff RIGHT
// Byte3 Y方向 UP   0x00-0x7f-0xff DOWN


#define VID2F24PID0039		9				//Matflash F300 Elite
// Matflash F300 Elite
//
//VID: 0x2F24 PID: 0x39 Connected.
//BUF: 00 00 0F 80 80 80 80 00　←挿した後の初期値
//BUF: 00 00 00 80 80 80 80 00　←十字キー[上]を押した ★
//BUF: 00 00 04 80 80 80 80 00　←十字キー[下]を押した ★
//BUF: 00 00 06 80 80 80 80 00　←十字キー[左]を押した ★
//BUF: 00 00 02 80 80 80 80 FF　←十字キー[右]を押した ★
//BUF: 02 00 0F 80 80 80 80 00　←ボタン[A]を押した ★A(TRIGGER1)
//BUF: 04 00 0F 80 80 80 80 00　←ボタン[B]を押した ★B(TRIGGER3)
//BUF: 80 00 0F 80 80 80 80 00　←ボタン[RT]を押した ◎A(TRIGGER1)
//BUF: 40 00 0F 80 80 80 80 00　←ボタン[LT]を押した
//BUF: 01 00 0F 80 80 80 80 00　←ボタン[X]を押した ◎B(TRIGGER3)
//BUF: 08 00 0F 80 80 80 80 00　←ボタン[Y]を押した ◎A(TRIGGER1)
//BUF: 20 00 0F 80 80 80 80 00　←ボタン[RB]を押した ◎B(TRIGGER3)
//BUF: 10 00 0F 80 80 80 80 00　←ボタン[LB]を押した
//BUF: 00 02 0F 80 80 80 80 00　←ボタン[START]を押した ★START
//BUF: 00 01 0F 80 80 80 80 00　←ボタン[SELECT]を押した ★SELECT
//BUF: 00 10 0F 80 80 80 80 00　←ボタン[HOME]を押した
//
// Byte0 button [RT LT RB LB   | Y B A     X      ]
// Byte1 button [0  0  0  HOME | 0 0 START SELECT ]
// Byte2 HAT


#define VID054CPID09CC		10				//PS4 DUALSHOCK 4 (CUH-ZCT2J)
#define VID0F0DPID00ED		11				//HORI FIGHTING STICK MINI
// PS4 DUALSHOCK 4 (CUH-ZCT2J)
//
//VID: 0x54C PID: 0x9CC Connected.
//BUF: 01 7F 7F 7F 7F 08 00 38　←挿した後の初期値
//
// Byte1 L Stick X方向 LEFT 0x00-0x7f-0xff RIGHT
// Byte2 L Stick Y方向 UP   0x00-0x7f-0xff DOWN
// Byte3 R Stick X方向 LEFT 0x00-0x7f-0xff RIGHT
// Byte4 R Stick Y方向 UP   0x00-0x7f-0xff DOWN
// Byte5 button [ △ ○ × □ | HAT[4bit] ]
// Byte6 button [ RSTICK LSTICK OPTIONS SHARE | R2 L2 R1 L1 ]

//#define VID_PID_UNKNOWN		128				//Unknown Direct Input

// Byte1 X方向 LEFT 0x00-0x7f-0xff RIGHT
// Byte2 Y方向 UP   0x00-0x7f-0xff DOWN
// Byte3 X方向 LEFT 0x00-0x7f-0xff RIGHT
// Byte4 Y方向 UP   0x00-0x7f-0xff DOWN
// Byte5 0x1F A / 0x2F B
// Byte6 0x20 Start / 0x10 Select

// Byte0 button [ BLUE PINK 0 A | E B C     F ]
// Byte1 button [ 0    0    0 0 | 0 0 WHITE D ]

// VID&PIDのテーブル
const  uint16_t  tVID[] = {0x0CA3, 0x0CA3, 0x0F0D, 0x0810, 0x054c, 0x2DC8, 0x0CA3, 0x0AE4, 0x0AE4, 0x2F24, 0x054C, 0x0F0D};
const  uint16_t  tPID[] = {0x0025, 0x0024, 0x0138, 0xE501, 0x0CDA, 0x2101, 0x0027, 0x0702, 0x0703, 0x0039, 0x09CC, 0x00ED};



bool flagConnected;

// M5Faces GamePad key Assign
// UP     bit0
// DOWN   bit1
// LEFT   bit2
// RIGHT  bit3
// A      bit4
// B      bit5
// Select bit6
// Start  bit7


#ifdef FACES_GAMEPAD_MODE
unsigned char keycode = 0xFF;
#else
unsigned char keycode = 0x00;
#endif

unsigned char tKeycode = 0xFF;

#include "le3dp_rptparser.h"

// Satisfy the IDE, which needs to see the include statment in the ino too.
#ifdef dobogusinclude
#include <spi4teensy3.h>
#endif
#include <SPI.h>

// M5 Faces Game Padモードでのビット配置
#define M5Faces_Up		0xfe
#define M5Faces_Down	0xfd
#define M5Faces_Left	0xfb
#define M5Faces_Right	0xf7
#define M5Faces_A		0xef
#define M5Faces_B		0xdf
#define M5Faces_Select	0xbf
#define M5Faces_Start	0x7f

void MakeKeyData_Hat(unsigned char data){
// Hat Dataのデコード
	if (data == 1 ) tKeycode = tKeycode & (M5Faces_Up & M5Faces_Right);
	if (data == 2 ) tKeycode = tKeycode & M5Faces_Right;
	if (data == 3 ) tKeycode = tKeycode & (M5Faces_Down & M5Faces_Right);
	if (data == 4 ) tKeycode = tKeycode & M5Faces_Down;

	if (data == 5 ) tKeycode = tKeycode & (M5Faces_Down & M5Faces_Left);
	if (data == 6 ) tKeycode = tKeycode & M5Faces_Left;
	if (data == 7 ) tKeycode = tKeycode & (M5Faces_Up & M5Faces_Left);
	if (data == 0 ) tKeycode = tKeycode & M5Faces_Up;
}

void MakeKeyData_XY(unsigned char x_data,unsigned char y_data){
// Hat Dataのデコード
	if (x_data < 0x40) tKeycode = tKeycode & M5Faces_Left;
	if (x_data > 0xC0) tKeycode = tKeycode & M5Faces_Right;

	if (y_data < 0x40) tKeycode = tKeycode & M5Faces_Up;
	if (y_data > 0xC0) tKeycode = tKeycode & M5Faces_Down;
}

void MakeKeyData_HatPSX(unsigned char data){
// Hat Dataのデコード(PSX)
	if ((data & 0x0c) == 0x00) tKeycode = tKeycode & M5Faces_Left;
	if ((data & 0x0c) == 0x08) tKeycode = tKeycode & M5Faces_Right;

	if ((data & 0x30) == 0x00) tKeycode = tKeycode & M5Faces_Up;
	if ((data & 0x30) == 0x20) tKeycode = tKeycode & M5Faces_Down;

}

void MakeKeyData_AB(unsigned char data_a,unsigned char bit_a,unsigned char data_b,unsigned char bit_b){
// AB Dataのデコード
	if (Get_Bit(data_a,bit_a) != 0x00) tKeycode = tKeycode & M5Faces_A;
	if (Get_Bit(data_b,bit_b) != 0x00) tKeycode = tKeycode & M5Faces_B;
}

void MakeKeyData_SelStart(unsigned char data_sel,unsigned char bit_sel,unsigned char data_start,unsigned char bit_start){
// Select Start Dataのデコード
	if (Get_Bit(data_sel,bit_sel) != 0x00) tKeycode = tKeycode & M5Faces_Select;
	if (Get_Bit(data_start,bit_start) != 0x00) tKeycode = tKeycode & M5Faces_Start;
}


void requestEvent()
{
	Wire.write(keycode);
}

USB Usb;
USBHub Hub(&Usb);
HIDUniversal Hid(&Usb);
JoystickEvents JoyEvents;
JoystickReportParser Joy(&JoyEvents);



void setup()
{
//ポート設定
	DDRB = DDRB | 0x10;			//PB4 OUTPUT (USB RST)
	DDRB = DDRB & 0xDF;			//PB5 INPUT (INT) 
	PORTB = PORTB | 0x20;		//PB5 Pullup
	PORTB = PORTB & 0xE0;		//PB4 Low->USB Unit Reset

	DDRD = DDRD|0x90;			//PD7 DSUB COM PD4: OUTPUT (M5 KEYISR)
	DDRD = DDRD&0xFC;			//PD0-1:INPUT (TRIG0/1)
	PORTD = PORTD | 0x13;		//PD4:H ,PD1-0 Pull UP
	PORTD = PORTD & 0x7f;		//PD7:L4

	DDRF = DDRF & 0x0F;			//PF4-7 INPUT (DSUB)
	PORTF = PORTF | 0xF0;		//PF4-7 Pullup

	PORTB = PORTB | 0x10;		//PB4 HIGH

//グローバル変数初期化
	flagConnected = false;

//I2C有効、割り込み使用
	Wire.begin(FACES_KEYBOARD_I2C_ADDR);
	Wire.onRequest(requestEvent);

//UART一応有効化(ファーム書き換え時に困るため）
	Serial.begin( 115200 );

	#ifdef DEBUG_PRINT 
	#if !defined(__MIPSEL__)
//  while (!Serial); // Wait for serial port to connect - used on Leonardo, Teensy and other boards with built-in USB CDC serial connection
	#endif
	Serial.println("Start");
	#endif

	if (Usb.Init() == -1){
		#ifdef DEBUG_PRINT 
		Serial.println("OSC did not start.");
		#endif
	}
	delay( 200 );

	if (!Hid.SetReportParser(0, &Joy))
	ErrorMessage<uint8_t>(PSTR("SetReportParser"), 1  );
}

void loop()
{
// ループ処理

	uint8_t rcode = 0;
	byte num_conf = 0;
	USB_DEVICE_DESCRIPTOR buf;
	int i;


	Usb.Task();
	if( Usb.getUsbTaskState() == USB_STATE_RUNNING ) {
// USBのINTERVALアクセスが始まると以下のルーチンが実行される

//コントローラの１回目の接続時のみ対応コントローラかどうかのチェックを行う。
//対応しているコントローラの場合対応した番号を割り付ける
		if (flagConnected == false) {
			flagConnected = true;
			rcode = Usb.getDevDescr(1, 0, 0x12, ( uint8_t *)&buf );
			if( rcode ) {
				//普通はここには来ない、
				//USB Device Descriptorが取得出来なかった場合など
				#ifdef DEBUG_PRINT 
				Serial.print("USB ERROR: "); Serial.println( rcode );
				#endif
				while (1);
			}
			#ifdef DEBUG_PRINT 
			Serial.print("VID: 0x"); Serial.print(buf.idVendor, HEX);
			Serial.print(" PID: 0x"); Serial.print(buf.idProduct, HEX);
			Serial.println (" Connected.");
			#endif

//
			JoyCl = 0xFF;
			//対応コントローラチェック
			//非対応コントローラはVIDとPIDをテーブルに追加して、
			//RAW Dataのデコードを追記すれば対応可能
			for (i = 0 ;i<JoyClMax+1;i++){
				if ((buf.idVendor == tVID[i]) && (buf.idProduct == tPID[i])) {
					JoyCl = i;
					#ifdef DEBUG_PRINT 
					Serial.println("Support USB JoyStick");
					Serial.print("ID: ");
					Serial.println(JoyCl);
					#endif
				}
			}

		}
	}else{
		flagConnected = false;
	}

// Direction button
}

void JoystickEvents::OnGamePadChanged(const GamePadEventData *evt)
{
// USBのINTERVALデータが一つ前と異なる場合、変化がある場合ここがCallされる。

	//RAW DATA出力（デバッグ用）
	#ifdef USB_RAW_DISPLAY
	Serial.print("BUF: ");
	PrintHex<uint8_t>(evt->raw_data[0], 0x0);
	PrintHex<uint8_t>(evt->raw_data[1], 0x0);
	PrintHex<uint8_t>(evt->raw_data[2], 0x0);
	PrintHex<uint8_t>(evt->raw_data[3], 0x0);
	PrintHex<uint8_t>(evt->raw_data[4], 0x0);
	PrintHex<uint8_t>(evt->raw_data[5], 0x0);
	PrintHex<uint8_t>(evt->raw_data[6], 0x0);
	PrintHex<uint8_t>(evt->raw_data[7], 0x0);
	Serial.println("");
	#endif
	
	tKeycode = 0xff;			//PADデータ初期値
	switch(JoyCl)
	{
		case VID0CA3PID0025: 	//MD PAD USB (MK-16500)
		MakeKeyData_XY(evt->raw_data[3],evt->raw_data[4]);
		MakeKeyData_AB(evt->raw_data[5],6,evt->raw_data[5],5);			// A:A B:B
		MakeKeyData_SelStart(evt->raw_data[6],1,evt->raw_data[6],5);	// SEL:C START:START
		break;

		case VID0CA3PID0024: 	//MD 6B PAD USB (HAA-2522)
		MakeKeyData_XY(evt->raw_data[3],evt->raw_data[4]);
		MakeKeyData_AB(evt->raw_data[5],6,evt->raw_data[5],5);			// A:A B:B
		MakeKeyData_SelStart(evt->raw_data[6],4,evt->raw_data[6],5);	// SEL:SELECT START:START
		break;

		case VID0F0DPID0138: 	//KONAMI PCEmini Controller(HT-002)
		MakeKeyData_Hat(evt->raw_data[2]);
		MakeKeyData_AB(evt->raw_data[0],2,evt->raw_data[0],1);			// A:I B:II
		MakeKeyData_SelStart(evt->raw_data[1],0,evt->raw_data[6],1);	// SEL:SELECT START:START
		break;

		case VID0810PIDE501: 	//NB NES USB Controller
		MakeKeyData_XY(evt->raw_data[3],evt->raw_data[4]);
		MakeKeyData_AB(evt->raw_data[5],5,evt->raw_data[5],4);			// A:A B:B
		MakeKeyData_SelStart(evt->raw_data[6],4,evt->raw_data[6],5);	// SEL:SELECT START:START
		break;

		case VID054CPID0CDA: 	//SONY PSX mini Controller (SCPH-1000R)
		MakeKeyData_HatPSX(evt->raw_data[1]);
		MakeKeyData_AB(evt->raw_data[0],1,evt->raw_data[0],2);				// A:× B:○
		MakeKeyData_SelStart(evt->raw_data[1],0,evt->raw_data[1],1);		// SEL:SELECT START:START
		break;

		case VID2DC8PID2101:	//8BitDo SN30 Pro
		MakeKeyData_Hat(evt->raw_data[3]);
		MakeKeyData_AB(evt->raw_data[1],4,evt->raw_data[1],3);				// A:Y B:X
		MakeKeyData_AB(evt->raw_data[1],0,evt->raw_data[1],1);				// A:A B:B
		MakeKeyData_SelStart(evt->raw_data[2],2,evt->raw_data[2],3);		// SEL:SELECT START:START
		break;

		case VID0CA3PID0027:	//SEGA アストロシティミニ コントロールパッド
		MakeKeyData_XY(evt->raw_data[3],evt->raw_data[4]);
		MakeKeyData_AB(evt->raw_data[5],5,evt->raw_data[5],6);			// A:E B:D
		MakeKeyData_AB(evt->raw_data[6],0,evt->raw_data[6],1);			// A:C B:F
		MakeKeyData_AB(evt->raw_data[5],7,evt->raw_data[5],4);			// A:A B:B
		MakeKeyData_SelStart(evt->raw_data[6],4,evt->raw_data[6],5);	// SEL:CREDIT START:START
		break;

		case VID0AE4PID0702:	//TAITO イーグレットツーミニ コントロールパッド
		case VID0AE4PID0703:	//TAITO イーグレットツーミニ コントロールパネル
		MakeKeyData_XY(evt->raw_data[2],evt->raw_data[3]);
		MakeKeyData_AB(evt->raw_data[0],4,evt->raw_data[0],2);			// A:A B:B
		MakeKeyData_AB(evt->raw_data[0],1,evt->raw_data[1],0);			// A:C B:D
		MakeKeyData_AB(evt->raw_data[0],3,evt->raw_data[0],0);			// A:E B:F
		MakeKeyData_SelStart(evt->raw_data[0],6,evt->raw_data[0],7);	// SEL:PINK START:BLUE
		break;

		case VID2F24PID0039:	//Matflash F300 Elite
		MakeKeyData_Hat(evt->raw_data[2]);
		MakeKeyData_AB(evt->raw_data[0],1,evt->raw_data[0],2);				// A:A B:B
		MakeKeyData_AB(evt->raw_data[0],7,evt->raw_data[0],5);				// A:RT B:RB
		MakeKeyData_AB(evt->raw_data[0],3,evt->raw_data[0],0);				// A:Y B:X
		MakeKeyData_SelStart(evt->raw_data[1],0,evt->raw_data[1],1);		// SEL:SELECT START:START
		break;

		case VID054CPID09CC:	//PS4 DUALSHOCK 4 (CUH-ZCT2J)
		case VID0F0DPID00ED:	//HORI FIGHTING STICK MINI
		MakeKeyData_Hat((evt->raw_data[5]) & 0x0f);
		MakeKeyData_AB(evt->raw_data[5],5,evt->raw_data[5],6);				// A:× B:○
		MakeKeyData_SelStart(evt->raw_data[6],4,evt->raw_data[6],5);		// SEL:SHARE START:OPTION
		break;

		default:				//不明コントローラ
		MakeKeyData_XY(evt->raw_data[0],evt->raw_data[1]);
		MakeKeyData_AB(evt->raw_data[2],1,evt->raw_data[2],0);				// A:A B:B
		MakeKeyData_SelStart(evt->raw_data[2],2,evt->raw_data[2],3);		// SEL:C START:START
		break;

	}

	if (tKeycode != 0xff) IRQ_0;		//キー入力あり
	else IRQ_1;

	keycode = 	tKeycode;				//I2C Dataへ転送
}

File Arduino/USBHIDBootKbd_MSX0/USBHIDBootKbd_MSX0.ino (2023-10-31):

////////////////////////////////////////////////////////////////////////
//
// M5 Faces Keyboard & Game Pad Emulator
// MSX0 USB-Keyboard MBUS Stack
// Copyright 2023 @V9938
//	
//	23/04/06 V1.0		1st version
//	23/10/26 V1.1		Support MSX0 official Release version
//
////////////////////////////////////////////////////////////////////////
// 下記ライブラリを使用しています。
// USB Host Shield library Version 2.0
// https://chome.nerpa.tech/arduino_usb_host_shield_projects/
////////////////////////////////////////////////////////////////////////


#include <hidboot.h>
#include <usbhub.h>
#include <Wire.h>

// Satisfy the IDE, which needs to see the include statment in the ino too.
#ifdef dobogusinclude
#include <spi4teensy3.h>
#endif
#include <SPI.h>

#define Set_Bit(val, bitn)    (val |=(1<<(bitn)))
#define Clr_Bit(val, bitn)     (val&=~(1<<(bitn)))
#define Get_Bit(val, bitn)    (val &(1<<(bitn)) )


// UARTにデバッグMessageを表示するか（通常は無効)
//#define DEBUG_PRINT 1
// I2Cのアドレス
#define FACES_KEYBOARD_I2C_ADDR 0x08

// M5キー割り込みの出力のポート
#define IRQ_1 Set_Bit(PORTD,4)
#define IRQ_0 Clr_Bit(PORTD,4)

// グローバル変数
unsigned char hadPressed = 0;			// ボタン押されたかフラグ
unsigned char firstBoot = 0;			// 書き込みモードのBUSY OUTフラグ
unsigned char stringBuffer[128];		// KEYBOARD入力値を貯めるバッファー
unsigned char strBufEnd;				// バッファー最終値
unsigned char strBufPointer;			// バッファー現在値
unsigned char padMode;					// PADモードかどうかのフラグ
unsigned char padData;					// I2C送信値 0x7f以上をMSX0起動時に送るとGAMEPADモードになる
unsigned char tDataOld;					// PADの前入力値
unsigned char byteDAT[32];				// I2C 受信buffer


// I2C 0x08の割り込み(read)処理
void requestEvent()
{

	if (padMode == 1){
		//PADモード：データをそのまま送る
		if(firstBoot == 1) {
			//識別（パッドモード）
			Wire.write(0xff);
			firstBoot = 0;
		}else{
			Wire.write(padData);
		}
	}else{
		//Keyboardモード：KeyBufferに貯めたデータを順次送る

		if(firstBoot == 1) {
			//識別（キーボードモード）
			Wire.write(0x00);
			firstBoot = 0;
		}else{
			// キーが押された履歴チェック
			if (hadPressed == 1){
				Wire.write(stringBuffer[strBufPointer]);
				strBufPointer++;
				if (strBufEnd == strBufPointer) {
					hadPressed = 0;
					IRQ_1;
				}
			}
		}
	}
}

// I2C 0x08の割り込み(Write)処理
void sendEvent()
{
	while(Wire.available()){
		// 
		if (Wire.read() == 0xfe){
			firstBoot = 1;
	  	}
	}
}

// Class定義
class KbdRptParser : public KeyboardReportParser
{
	void PrintKey(uint8_t mod, uint8_t key);

protected:
	void OnControlKeysChanged(uint8_t before, uint8_t after);

	void OnKeyDown	(uint8_t mod, uint8_t key);
	void OnKeyUp	(uint8_t mod, uint8_t key);
	void OnKeyPressed(uint8_t key);
};


void KbdRptParser::PrintKey(uint8_t m, uint8_t key)
{
// キーボード入力の表示（デバッグ用)
	#ifdef DEBUG_PRINT 
	MODIFIERKEYS mod;
	*((uint8_t*)&mod) = m;
	Serial.print((mod.bmLeftCtrl   == 1) ? "C" : " ");
	Serial.print((mod.bmLeftShift  == 1) ? "S" : " ");
	Serial.print((mod.bmLeftAlt    == 1) ? "A" : " ");
	Serial.print((mod.bmLeftGUI    == 1) ? "G" : " ");

	Serial.print(" >");
	PrintHex<uint8_t>(key, 0x80);
	Serial.print("< ");

	Serial.print((mod.bmRightCtrl   == 1) ? "C" : " ");
	Serial.print((mod.bmRightShift  == 1) ? "S" : " ");
	Serial.print((mod.bmRightAlt    == 1) ? "A" : " ");
	Serial.println((mod.bmRightGUI    == 1) ? "G" : " ");
	#endif

};
void KeyDataUpdate(unsigned char c){
// キーボードバッファーへの一文字入力
	stringBuffer[strBufEnd] = c;
	strBufEnd++;						//toDO:Overflow対策

	hadPressed = 1;
	IRQ_0;

}
void KeyDataStrUpdate(String str){
// キーボードバッファーへの文字列入力(MAX16文字)

	unsigned char chrs[16];
	int i;
	str.toCharArray(chrs,16);  					//Strクラスから変換

	for (i=0;i<str.length();i++){				//文字コピー
		if (chrs[i] == 0x0a){
			stringBuffer[strBufEnd] = 0x0d;
		}else{
			stringBuffer[strBufEnd] = chrs[i];
		}
		strBufEnd++;
	}

	hadPressed = 1;								//キーデータあり
	IRQ_0;										//キー入力をM5に通知
}



void KbdRptParser::OnKeyDown(uint8_t mod, uint8_t key)
{
// キーボードが押された場合に実行される処理

// キーデータについては、別データを参照
//	USBキーボード(JP)とM5 Facesのキーコード変換テーブル (シフトキーなし）
	const uint8_t KeyboardTable[256]       PROGMEM = { 
//         0     1     2     3     4     5     6     7     8     9     A     B     C     D     E     F
		0x00, 0x00, 0x00, 0x00,  'a',  'b',  'c',  'd',  'e',  'f',  'g',  'h',  'i',  'j',  'k',  'l', 	// 0x00
		'm',  'n',  'o',  'p',  'q',  'r',  's',  't',  'u',  'v',  'w',  'x',  'y',  'z',  '1',  '2', 		// 0x10
		 '3',  '4',  '5',  '6',  '7',  '8',  '9',  '0', 0x0d, 0x1b, 0x08, 0x09, 0x20, 0x2d, 0xde, 0x00, 	// 0x20
		0xdb, 0x00, 0xdd, 0x3b, 0x3a, 0x00, 0x2c, 0x2e, 0x2f, 0xf2, 0x00, 0x00, 0x00, 0x00, 0x00, 0x00, 	// 0x30
		0x00, 0x00, 0x00, 0x00, 0x7b, 0xf4, 0x00, 0x00, 0xbc, 0x00, 0x00, 0x00, 0x08, 0x00, 0x00, 0xc1, 	// 0x40
		0xbf, 0xc0, 0xb7, 0x00, 0x2f, 0x2a, 0x2d, 0x2b, 0x0d, 0x00, 0xfd, 0x00, 0xfb, 0x00, 0xf7, 0x00, 	// 0x50
		0xfe, 0x00, 0x00, 0x00, 0x00, 0x00, 0x00, 0x00, 0x00, 0x00, 0x00, 0x00, 0x00, 0x00, 0x00, 0x00, 	// 0x60 (TENKEY NUMLOCK OFF)
		0x00, 0x00, 0x00, 0x00, 0x00, 0x00, 0x00, 0x00, 0x00, 0x00, 0x00, 0x00, 0x00, 0x00, 0x00, 0x00, 	// 0x70
		0x00, 0x00, 0x00, 0x00, 0x00, 0x00, 0x00, 0x5c, 0xf3, 0x5c, 0x00, 0x00, 0x00, 0x00, 0x00, 0x00, 	// 0x80
		0x00, 0x00, 0x00, 0x00, 0x00, 0x00, 0x00, 0x00, 0x00, 0x00, 0x00, 0x00, 0x00, 0x00, 0x00, 0x00, 	// 0x90
		0x00, 0x00, 0x00, 0x00, 0x00, 0x00, 0x00, 0x00, 0x00, 0x00, 0x00, 0x00, 0x00, 0x00, 0x00, 0x00, 	// 0xA0
		0x00, 0x00, 0x00, 0x00, 0x00, 0x00, 0x00, 0x00, 0x00, 0x00, 0x00, 0x00, 0x00, 0x00, 0x00, 0x00, 	// 0xB0
		0x00, 0x00, 0x00, 0x00, 0x00, 0x00, 0x00, 0x00, 0x00, 0x00, 0x00, 0x00, 0x00, 0x00, 0x00, 0x00, 	// 0xC0
		0x00, 0x00, 0x00, 0x00, 0x00, 0x00, 0x00, 0x00, 0x00, 0x00, 0x00, 0x00, 0x00, 0x00, 0x00, 0x00, 	// 0xD0
		0x00, 0x00, 0x00, 0x00, 0x00, 0x00, 0x00, 0x00, 0x00, 0x00, 0x00, 0x00, 0x00, 0x00, 0x00, 0x00, 	// 0xE0
		0x00, 0x00, 0x00, 0x00, 0x00, 0x00, 0x00, 0x00, 0x00, 0x00, 0x00, 0x00, 0x00, 0x00, 0x00, 0x00   	// 0xF0
	};
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

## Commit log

2023-04-11 1st Release
    [MSX0KEYTABLE.xlsx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]
2023-04-24 added assembly instructions manual.
    ユーザ組み立て用のマニュアルを追加しました。
    [m5stack-Stack_RevB.stl]
2023-04-24 Update Assembly.md
    Fixed typo
2023-05-05 Update USBHIDPad2MSX0.ino
    以下のUSBコントローラをサポートしました。
    - 8BitDo SN30 Pro
    - SEGA アストロシティミニ コントロールパッド
    - TAITO イーグレットツーミニ コントロールパッド
    - TAITO イーグレットツーミニ コントロールパネル
    - Matflash F300 Elite
    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
2023-05-05 Update USBHIDPad2MSX0.ino
    - HORI FIGHTING STICK MINI
    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
2023-05-05 Fixed missing HORI FIGHTING STICK MINI
    HORI FIGHTING STICK MINIを検出出来ないバグを修正
    [USBHIDPad2MSX0.ino]
2023-05-22 Update README.md
    販売情報とFirmwareの説明を追加しました。
2023-09-14 Update README.md
    MSX0製品版対応について追記
2023-10-26 Update Arduino sketch
    MSX0公式リリース版正式対応に伴うsketchの更新
    旧キーボードモードでの動作であることを明記
2023-10-31 Fixed something typo
    いくつかの TYPOと組み立て説明書のリンクミスを修正しました。
    （Firmware本体には修正はありません)
    [USBHIDBootKbd_MSX0.ino]
